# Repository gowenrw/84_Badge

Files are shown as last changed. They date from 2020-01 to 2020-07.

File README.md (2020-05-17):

# 84_Badge

This is where all the files for 84_Badge will be stored.  
This includes code and art and cad and fab files.  All the things.

View the web based Documentation here https://84badge.com

## File Structure

This is the file structure of this repository

* [/](/README.md) - YOU ARE HERE
* [/art/](./art/) - Artwork and other graphics created by this project
  * ./inspiration/ - Art and graphics pulled from other sources used as inspiration for this project
* [/code/](./code/) - All project related Code / Firmware
  * ./dev/ - Code folder for initial development PCB(s)
  * ./prod/ - Code folder for the production PCB(s)
  * ./include/ - Common code includes (e.g. chipset drivers, etc.) used by the other code folders
* [/docs/](./docs/) - Documentation created by this project including web pages
* [/eda/](./eda/) - Electronic Design Automation files (i.e. KiCad)
  * ./dev/ - KiCad project folder for initial development PCB(s)
  * ./prod/ - KiCad project folder for the production PCB(s)
* [/reference_parts/](./reference_parts/) - Documentation pulled from other sources related to components
* [./README.md](/README.md) - This File
* [./LICENSE](/LICENSE) - Currently set to MIT

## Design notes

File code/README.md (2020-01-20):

# Code

This is where all the all project related Code / Firmware is located

## File Structure

This is the file structure of this repository

* [/](/README.md) - Home
* [/code/](/code/) - YOU ARE HERE
  * [/code/dev/](/code/dev/) - Code folder for initial development PCB(s)
  * [/code/prod/](/code/prod/) - Code folder for the production PCB(s)
  * [/code/include/](/code/include/) - Common code includes (e.g. chipset drivers, etc.) used by the other code folders

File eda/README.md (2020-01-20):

# Electronic Design Automation

This is where all the Electronic Design Automation files for the PCB(s) will be stored.
The EDA used is KiCad 5.x unless otherwise specified.

The KiCad projects have been configured to use local libraries for long term sustainability per the best practices listed [HERE](https://hackaday.com/2017/05/18/kicad-best-practises-library-management/) and elsewhere.

## File Structure

This is the file structure of this repository

* [/](/README.md) - Home
* [/eda](/eda/) - YOU ARE HERE
  * [/eda/dev/](/eda/dev/) - KiCad project folder for initial development PCB(s)
    * ./3d_models/ - This directory contains footprint 3d model files
    * ./gerber/ - This directory contains gerber formatted files for manufacturing
    * ./lib_fp/ - This directory contains footprint module directories
    * ./lib_sh/ - This directory contains schematic library files
    * ./snapshots/ - This directory contains prints of schematic / cad files and images of preview / final product
  * [/eda/prod/](/eda/prod/) - KiCad project folder for the production PCB(s)
    * ./3d_models/ - This directory contains footprint 3d model files
    * ./gerber/ - This directory contains gerber formatted files for manufacturing
    * ./lib_fp/ - This directory contains footprint module directories
    * ./lib_sh/ - This directory contains schematic library files
    * ./snapshots/ - This directory contains prints of schematic / cad files and images of preview / final product

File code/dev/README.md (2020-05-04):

# Code / Dev

Code folder for initial development PCB(s)

Currently contains example code for the 84 Badge development PCB

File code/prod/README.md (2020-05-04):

# Code / Prod

Code folder for the production PCB(s)

Currently contains the following code:
* Example code for the 84 badge PCB
* Production code for the 84 badge PCB

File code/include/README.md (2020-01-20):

# Code Includes

Common code includes (e.g. chipset drivers, etc.) used by the other code folders

This folder currently contains the CH55x micro controller include files taken from the [Blinkinlabs Repository](https://github.com/Blinkinlabs/ch554_sdcc)

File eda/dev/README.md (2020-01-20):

# Electronic Design Automation / Development PCB(s)

KiCad project folder for initial development PCB(s)

## File Structure

This is the file structure of this repository

* [/](/README.md) - Home
* [/eda](/eda/) - Electronic Design Automation files (i.e. KiCad)
  * [/eda/dev/](/eda/dev/) - YOU ARE HERE
    * ./<filename>.pro - project file. Holds parameters that apply to the entire project (e.g. schematic, PCB layout, etc.).
    * ./<filename>.sch - schematic file.
    * ./<filename>.kicad_pcb - the PCB New layout file.
    * ./<filename>.net - netlist in "Pcbnew" format
    * ./<filename>.bak - backup of schematic file.
    * ./<filename>.kicad_pcb-bak - backup of the new PCB layout file.
    * ./<filename>-cache.lib - a local cache copy of all the symbols used in the schematic
    * ./fp-lib-table - Footprint library list
    * ./sym-lib-table - Schematic library list
    * [./3d_models/](/eda/dev/3d_models/) - This directory contains footprint 3d model files
    * [./gerber/](/eda/dev/gerber/) - This directory contains gerber formatted files for manufacturing
    * [./lib_fp/](/eda/dev/lib_fp/) - This directory contains footprint module directories
    * [./lib_sh/](/eda/dev/lib_sh/) - This directory contains schematic library files
    * [./snapshots/](/eda/dev/snapshots/) - This directory contains prints of schematic / cad files and images of preview / final product

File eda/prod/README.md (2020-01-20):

# Electronic Design Automation / Production PCB(s)

KiCad project folder for the production PCB(s).

## File Structure

This is the file structure of this repository

* [/](/README.md) - Home
* [/eda](/eda/) - Electronic Design Automation files (i.e. KiCad)
  * [/eda/prod/](/eda/prod/) - YOU ARE HERE
    * ./<filename>.pro - project file. Holds parameters that apply to the entire project (e.g. schematic, PCB layout, etc.).
    * ./<filename>.sch - schematic file.
    * ./<filename>.kicad_pcb - the PCB New layout file.
    * ./<filename>.net - netlist in "Pcbnew" format
    * ./<filename>.bak - backup of schematic file.
    * ./<filename>.kicad_pcb-bak - backup of the new PCB layout file.
    * ./<filename>-cache.lib - a local cache copy of all the symbols used in the schematic
    * ./fp-lib-table - Footprint library list
    * ./sym-lib-table - Schematic library list
    * [./3d_models/](/eda/prod/3d_models/) - This directory contains footprint 3d model files
    * [./gerber/](/eda/prod/gerber/) - This directory contains gerber formatted files for manufacturing
    * [./lib_fp/](/eda/prod/lib_fp/) - This directory contains footprint module directories
    * [./lib_sh/](/eda/prod/lib_sh/) - This directory contains schematic library files
    * [./snapshots/](/eda/prod/snapshots/) - This directory contains prints of schematic / cad files and images of preview / final product

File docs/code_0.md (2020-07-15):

---
title: Code
has_children: true
nav_order: 4
---

# The Code of the 84 Badge

On this page I will review the badge code for both the development board and the badge PCB.
Both boards have the same electronics and the code works on both.
But the dev board code was to simply test the electronics and had more simple code compared to the badge code.

The Micro Controller used is a CH552G.
The CH55x series of Micro Controllers are based off of an ARM 8051 chipset and can be programmed using [Kiel C51](http://www.keil.com/c51/) or [SDCC](http://sdcc.sourceforge.net/).
I use SDCC (Small Device C Compiler) and will get into more specifics about that on the next page.

## Development board code

For the development board I just needed a quick and dirty test of the electronics.  So I created a simple blink program that will blink the LEDs by color group.

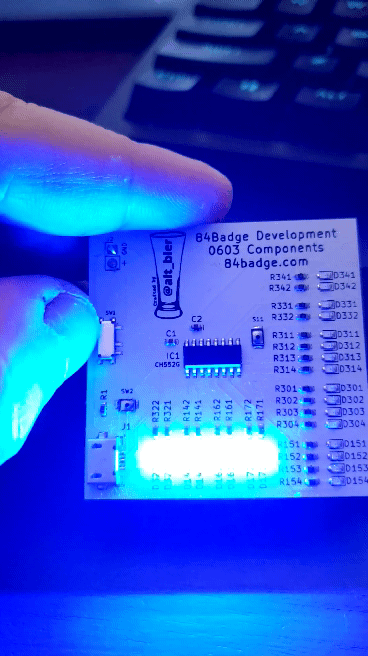
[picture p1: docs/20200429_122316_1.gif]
Dev_Board


The way the pins are laid out on the CH552G chip are by major pin and sub-pin (e.g. 1.1, 1.2, 3.1, 3.2, etc.).  

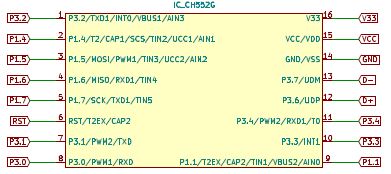
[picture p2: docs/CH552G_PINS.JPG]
CH552G_Pins


So the first things that I have to do is include the Micro Controller header file ch554.h and define the pins followed by setting the SBIT for those pins.  
Note: SBITs refer to the bits that have SFRs (special function registers) on the Micro Controller.

```c
#include <ch554.h>
.
.
#define LEDY30_PIN 0
#define LEDR31_PIN 1
#define LEDB32_PIN 2
#define LEDR33_PIN 3
#define LEDR34_PIN 4
.
.
// P1 = 0x90 P3 = 0xB0
SBIT(LEDY30, 0xB0, LEDY30_PIN);
SBIT(LEDR31, 0xB0, LEDR31_PIN);
SBIT(LEDB32, 0xB0, LEDB32_PIN);
SBIT(LEDR33, 0xB0, LEDR33_PIN);
SBIT(LEDR34, 0xB0, LEDR34_PIN);
.
.
```

With the preliminary setup done I can set up the main function and set those pins up as GPIO (general purpose input and output) pins by calling defined SFR references from the Micro Controller header file ch554.h

```c
void main() {
  .
  .
  // Configure pin 3.0 as GPIO output
  P3_MOD_OC = P3_MOD_OC & ~(1<<LEDY30_PIN);
  P3_DIR_PU = P3_DIR_PU |	(1<<LEDY30_PIN);
  // Configure pin 3.1 as GPIO output
  P3_MOD_OC = P3_MOD_OC & ~(1<<LEDR31_PIN);
  P3_DIR_PU = P3_DIR_PU |	(1<<LEDR31_PIN);
  // Configure pin 3.2 as GPIO output
  P3_MOD_OC = P3_MOD_OC & ~(1<<LEDB32_PIN);
  P3_DIR_PU = P3_DIR_PU |	(1<<LEDB32_PIN);
  // Configure pin 3.3 as GPIO output
  P3_MOD_OC = P3_MOD_OC & ~(1<<LEDR33_PIN);
  P3_DIR_PU = P3_DIR_PU |	(1<<LEDR33_PIN);
  // Configure pin 3.4 as GPIO output
  P3_MOD_OC = P3_MOD_OC & ~(1<<LEDR34_PIN);
  P3_DIR_PU = P3_DIR_PU |	(1<<LEDR34_PIN);
  .
  .
```

Here is an excerpt from ch554.h that defines those SFR references.

```c
SFR(P3_MOD_OC,	0x96);	// port 3 output mode: 0=push-pull, 1=open-drain
SFR(P3_DIR_PU,	0x97);	// port 3 direction for push-pull or pullup enable for open-drain
```

All that is left is to create a loop to turn the LEDs on and off with a delay.

```c
while (1) {
  // Setting the LEDs to on or off
  LEDY30 = 1;
  LEDY15 = 1;
  LEDR31 = 0;
  LEDR33 = 0;
  LEDR34 = 0;
  LEDB32 = 0;
  LEDB14 = 0;
  LEDB16 = 0;
  LEDB17 = 0;
  // Delay controls blink speed
  mDelaymS(300);
  .
  .
```

This is a simple but effective way for me to test out all the electronics on the board.

## 84 Badge code

For the badge code I needed to do a bit more work to get the groups of LEDs to light in the order I wanted them to fire for the effect I was going for.
In addition I needed to program the button to change LED modes and come up with a few different LED patterns to switch between.

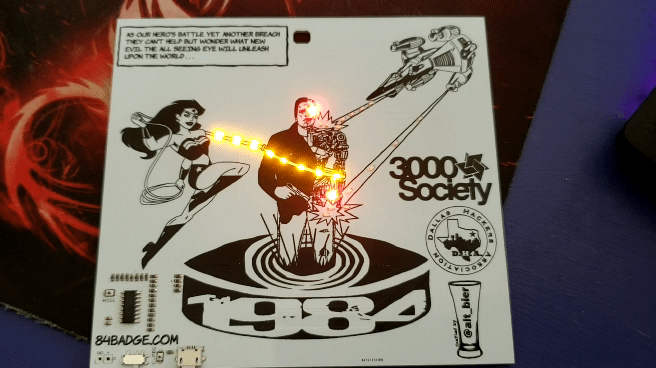
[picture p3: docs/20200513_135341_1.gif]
84_Badge_Board


I start this code the same way I did for the development board.
I include the Micro Controller header file ch554.h and define the pins followed by setting the SBIT for those pins.
For this board I must also define a couple of variables for the button operations.

```c
#include <ch554.h>
.
.
// define the sub-pins for pin 3
#define LEDY30_PIN 0
#define LEDR31_PIN 1
#define LEDB32_PIN 2
#define LEDR33_PIN 3
#define LEDR34_PIN 4
// define the sub-pins for pin 1
#define BUTTON11_PIN 1
.
.
// assign sub-pins to pins
// P1 = 0x90 P3 = 0xB0
SBIT(LEDY30, 0xB0, LEDY30_PIN);
SBIT(LEDR31, 0xB0, LEDR31_PIN);
SBIT(LEDB32, 0xB0, LEDB32_PIN);
SBIT(LEDR33, 0xB0, LEDR33_PIN);
SBIT(LEDR34, 0xB0, LEDR34_PIN);
SBIT(BUTTON11, 0x90, BUTTON11_PIN);
.
.
// 1 byte integer for putton push flag - no bool type available
uint8_t button11push=0;

// 1 byte integer for LED Mode (controlled by button)
// Modes 1 is the default start mode
uint8_t ledmode=1;
.
.
```

With the preliminary setup done I can set up the main function and set the LED pins up as GPIO (general purpose input and output) pins by calling defined SFR references from the Micro Controller header file ch554.h

```c
void main() {
  .
  .
    // setup pin 3
    // Configure pin 3.0 as GPIO output
    P3_MOD_OC = P3_MOD_OC & ~(1<<LEDY30_PIN);
    P3_DIR_PU = P3_DIR_PU |	(1<<LEDY30_PIN);
    // Configure pin 3.1 as GPIO output
    P3_MOD_OC = P3_MOD_OC & ~(1<<LEDR31_PIN);
    P3_DIR_PU = P3_DIR_PU |	(1<<LEDR31_PIN);
    // Configure pin 3.2 as GPIO output
    P3_MOD_OC = P3_MOD_OC & ~(1<<LEDB32_PIN);
    P3_DIR_PU = P3_DIR_PU |	(1<<LEDB32_PIN);
    // Configure pin 3.3 as GPIO output
    P3_MOD_OC = P3_MOD_OC & ~(1<<LEDR33_PIN);
    P3_DIR_PU = P3_DIR_PU |	(1<<LEDR33_PIN);
    // Configure pin 3.4 as GPIO output
    P3_MOD_OC = P3_MOD_OC & ~(1<<LEDR34_PIN);
    P3_DIR_PU = P3_DIR_PU |	(1<<LEDR34_PIN);
  .
  .
```

The last section of code took the most time as I had to create my loop and have it check for an LED mode and a button push which would change that LED mode.

```c
// ********************************
// ********* Primary Loop *********
// ********************************
while (1) {
    // ********************************
    // ********** LED MODE 3 **********
    // ********************************
    if (ledmode == 3) {
      // *****
      // ***** This mode keeps all LEDs ON
      // *****
      // Delay to display previous LED state
      mDelaymS(300);
      // If we see button push set button push flag
      if (BUTTON11 == 0) { button11push = 1; }
      // ***** Set LED states to on or off
      LEDY30 = 1, LEDY15 = 1, LEDR31 = 1, LEDR33 = 1, LEDR34 = 1, LEDB32 = 1, LEDB14 = 1, LEDB16 = 1, LEDB17 = 1;
      // ***** End of this LED mode
    }
    // ********************************
    // ********** LED MODE 2 **********
    // ********************************
    if (ledmode == 2) {
      .
      .
      // ***** End of this LED mode
      // *****
    }
    // ********************************
    // ***** LED MODE ADJUSTMENTS *****
    // ********************************
    // If button was pushed during the cycle above then flag should be set
    if (button11push == 1) {
      // Increase LED Mode value
      ledmode = ledmode + 1;
      // Check if LED Mode value is beyond max value and if so set to min value
      if (ledmode > 3) { ledmode = 1; }
      // Reset button push flag
      button11push = 0;
    }
    // ********************************
    // ****** END OF MODE LOOPS *******
    // ********************************
}
// ********************************
// ***** END OF PRIMARY LOOP ******
// ********************************
```

On each delay I would look for the button being pushed and if it was then I would set the variable button11push to 1 which would trigger the incrementing of the ledmode variable and the reset of the button11push variable at the end of the current LED mode loop iteration.

Most of the code is in the LED mode 1 which is the default LED mode and the one with the most complex pattern for the artwork effect.

In order to plan out how I wanted the LEDs to turn on or off for this LED mode I used google sheets.
I laid out the LEDs with conditional formatting and some scripting that would spit out the bit of code needed for each LED transition.

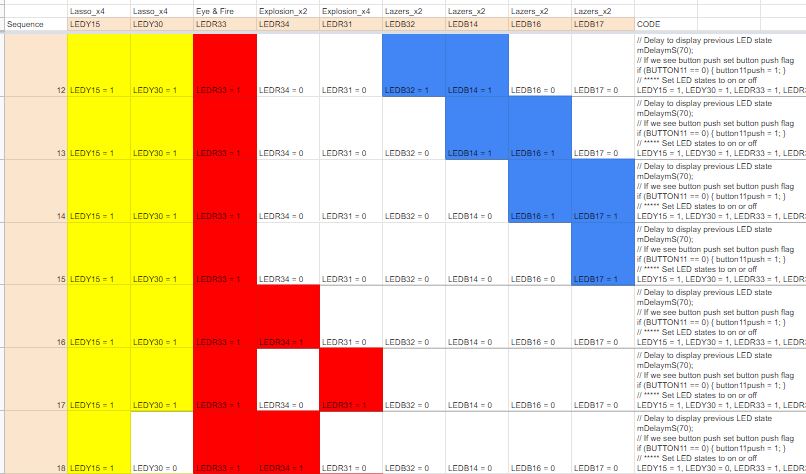
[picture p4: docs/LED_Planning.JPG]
LED_Planning


I think it turned out fairly well.
But I am looking at changing the yellow LEDs to use a PWM setting instead of simple on/off to provide more of a glowing effect.

This is the end of the code review.

Thanks for reading it.

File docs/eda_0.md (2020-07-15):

---
title: EDA
has_children: true
nav_order: 5
---

# The EDA work on the 84 Badge

This section is where I will review the Electronic Design Automation work done to produce the PCB(s) for the badge and its development board.

On this page I'll review the EDA software I used, the process I follow, and the file layout I used, and the reason I decided on a development board for the project.
On the following pages I will detail the schematic and PCB layouts of the 84 Badge and its development board.

## KiCad

I used [KiCad 5.1](https://kicad-pcb.org/) as my EDA program for this badge.

I configure my KiCad projects to use local libraries for long term sustainability per the best practices listed [HERE](https://hackaday.com/2017/05/18/kicad-best-practises-library-management/) and elsewhere.

Beyond the fact that I use some components that are not in the default KiCad libraries, copying the default components I use into my local project libraries ensures that if KiCad makes changes in the future, my projects will retain the original versions of these components keeping them compatible.

What this means for you is that when you download my project and open it up in KiCad you will have all the same exact component symbol and footprint and 3D model files available to you that I did when I created the project.

## My Process

The process I use when building a PCB in an KiCad is as follows:
* Create the file structure for the project
  * Note: I use a project template github repo to simplify this process as it has all the directories primed with README files.
* Build out the local libraries with any components I know I plan to use. (Others will be added to these libraries as identified)
  * Note: I use a project template github repo to simplify this process that contains most of the generic components I would use built into generic blank KiCad project files.
* Create the electrical schematic and output a netlist
* Create the PCB layout file starting with that netlist
  * This populates the PCB file with all the components from the schematic along with thier associated connection points that will need traces.
* Import the artwork into the silkscreen layers of the PCB
* Arrange the componets on the PCB and lay down the traces and vias
* Generate gerber output files of the PCB
* Send gerber files for manufacturing

## File Layout

This is the file layout I use for any PCB EDA project using KiCad.
Note that I break out development and production boards in thier own directory spaces.
* /eda/ - Electronic Design Automation files (i.e. KiCad)
  * /eda/dev/ - Development PCB
  * or
  * /eda/prod/ - Production PCB
    * ./<filename>.pro - project file. Holds parameters that apply to the entire project (e.g. schematic, PCB layout, etc.).
    * ./<filename>.sch - schematic file.
    * ./<filename>.kicad_pcb - the PCB New layout file.
    * ./<filename>.net - netlist in "Pcbnew" format
    * ./<filename>.bak - backup of schematic file.
    * ./<filename>.kicad_pcb-bak - backup of the new PCB layout file.
    * ./<filename>-cache.lib - a local cache copy of all the symbols used in the schematic
    * ./fp-lib-table - Footprint library list
    * ./sym-lib-table - Schematic library list
    * ./3d_models/ - This directory contains footprint 3d model files
    * ./gerber/ - This directory contains gerber formatted files for manufacturing
    * ./lib_fp/ - This directory contains footprint module directories
    * ./lib_sh/ - This directory contains schematic symbol library files
    * ./snapshots/ - This directory contains prints of schematic / cad files and images of preview / final product

## Development Board

I had an idea of how I wanted the electronics of the badge to be designed, but I needed to test it for several reasons.

This would be only my second time designing a board with the CH552G chip and this would triple the number of LEDs I had previously used.

In addition, I've never used components as small as the SMD 0603 before and had doubt's that I could place the parts by hand (Oh how I wish I could afford a pick and place machine).

The problem was that I was weeks away from having the artwork ready and needed to test my ideas sooner in case it didn't work and needed to be redesigned which might impact the artwork.

So rather than waiting for all the artwork to be done to do a prototype of the full badge I decided to make a development board that would have the same electronics but on a smaller scale without artwork.

It turns out that my electronics design was solid and I was able to place those tiny parts without too much trouble.
So, I just carried this forward to the badge design without change.

This means both the development board and the badge share the same electronics schematic and can use the same code.

This turned out to be an advantage as while I was waiting on the badge prototypes to arrive I was writing code and testing it using the development board.

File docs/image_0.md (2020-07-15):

---
title: Images
nav_order: 2
---

# Images of the badge

84 Badge Front

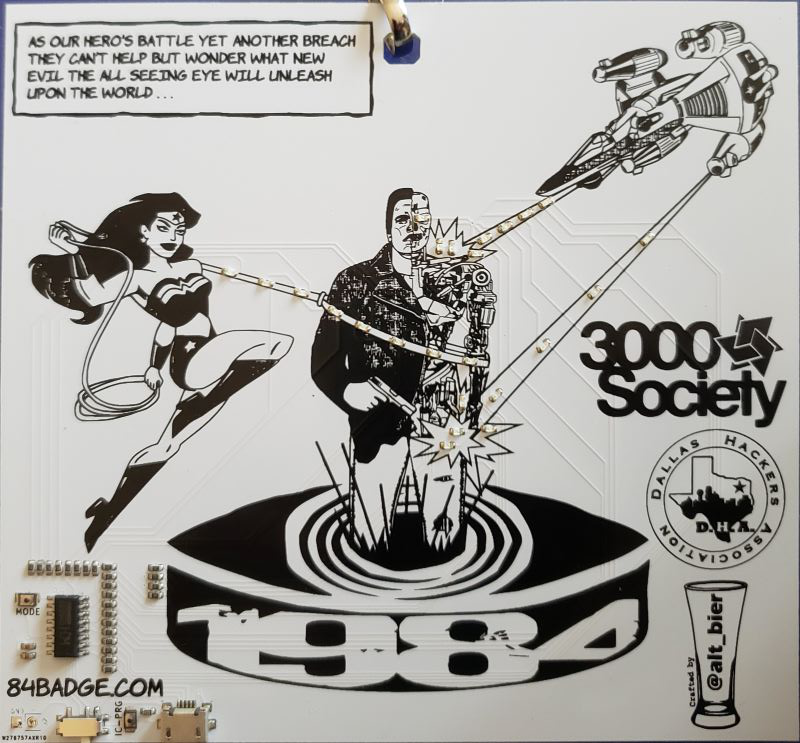
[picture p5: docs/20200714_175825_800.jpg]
Badge_front


84 Badge Back

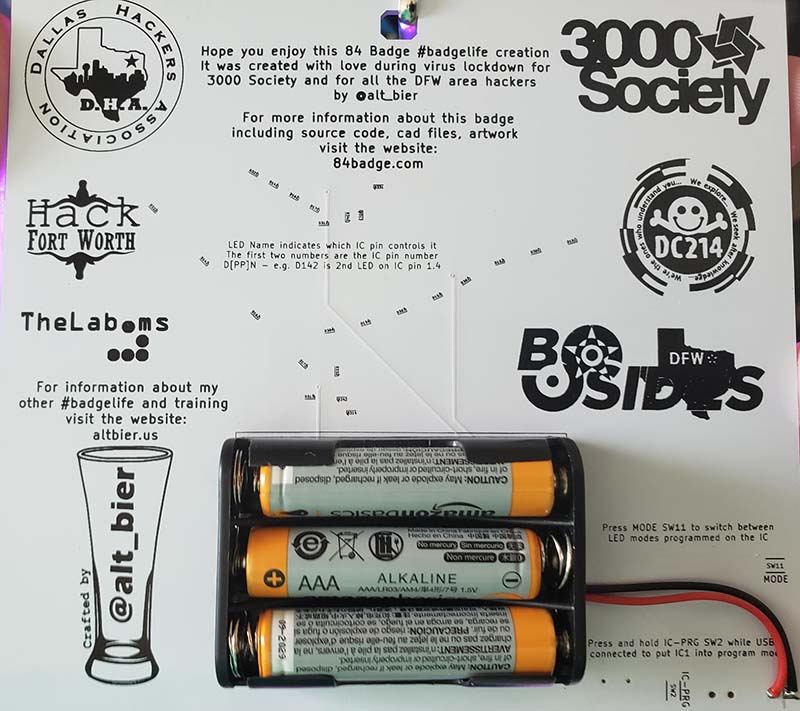
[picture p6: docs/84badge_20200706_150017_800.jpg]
Badge_back


84 Badge Front with all LEDs lit

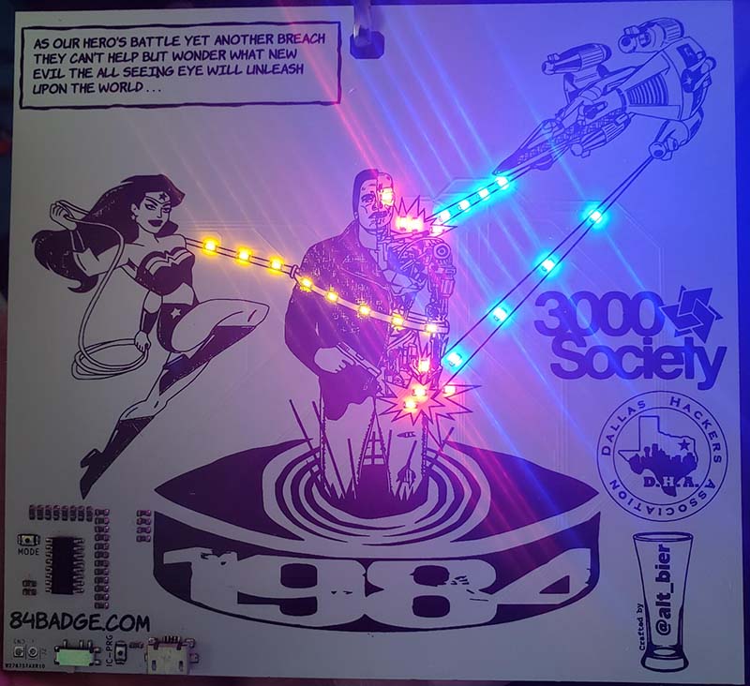
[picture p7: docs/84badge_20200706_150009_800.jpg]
Badge_front_lit


84 Badge Front with LEDs lit Animated

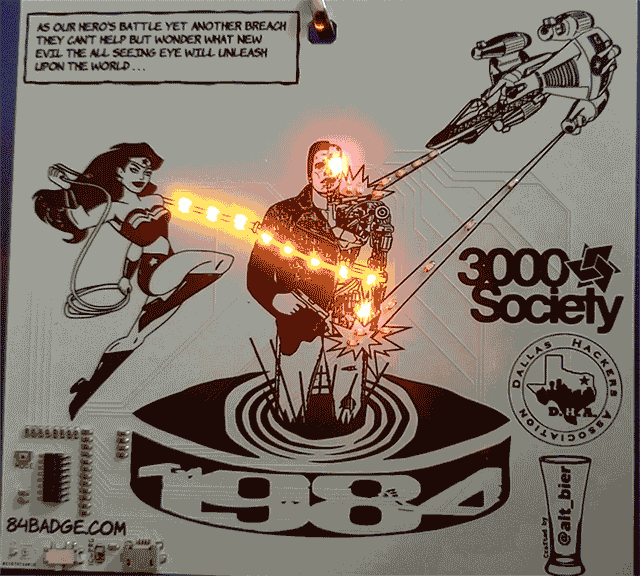
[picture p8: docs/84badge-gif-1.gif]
Badge_front_lit_gif


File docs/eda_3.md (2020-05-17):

---
title: Prod PCB
parent: EDA
nav_order: 3
---

# The EDA work on the 84 Badge - Prod PCB

The production board was a much more difficult proposition than the development board even with tested electronics.

I had to size it to present the artwork properly and fit all the components onto the PCB in such a way as to not detract from that artwork.

## PCB Layout

I decided to put most of the components in a corner where they would be out of the way of the artwork.

This had the added effect of becoming part of the artwork as the resistors appear to make a sort of box that Wonder Woman is launching herself from.

It also helped in my assembly since having most of the components in a small area of the PCB allowed my manual pick and place machine (my hands holding tweezers) to get the parts on the board faster.

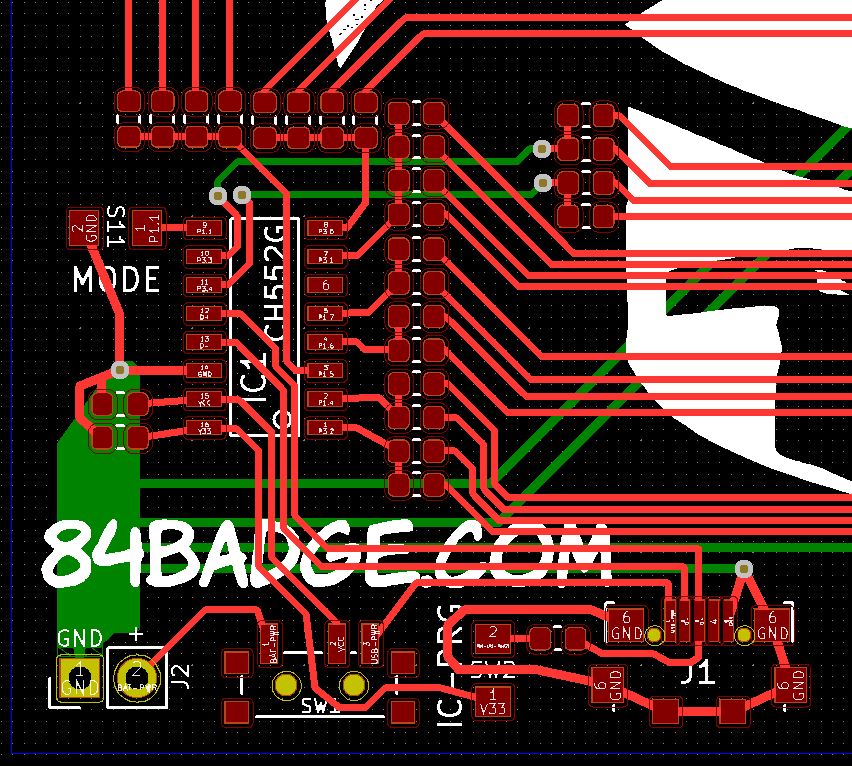
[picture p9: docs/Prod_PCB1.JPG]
Prod_PCB1


With most of the components in the corner done I focused on placing the LEDs next.

I had three different colors of LEDs grouped in different quantities to serve different purposes.  
So, I had to match up the exact LED I wanted in each place within the artwork of the board.

In some cases this was easy to do.

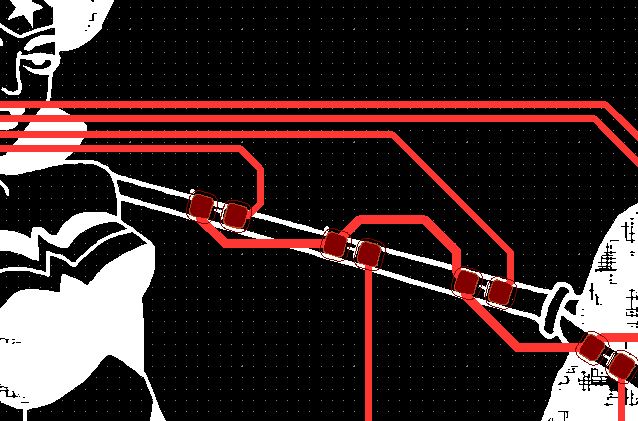
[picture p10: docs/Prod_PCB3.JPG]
Prod_PCB3


In some cases this was more difficult.

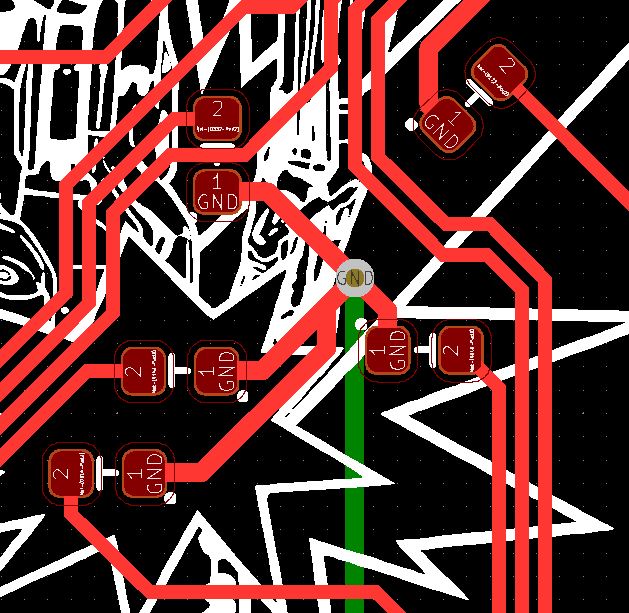
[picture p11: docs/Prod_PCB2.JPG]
Prod_PCB2


Once the LEDs were placed I had to run all the traces to them.

This was challenging because unlike on my development board I wasn't lining these up in neat lines but rather all over the board.

The help with this and avoid complicated routing I put the ground traces on the back of the board and used vias to connect them to the front.

To minimize the number of vias needed I chained several LED grounds together to be routed to a ground via.

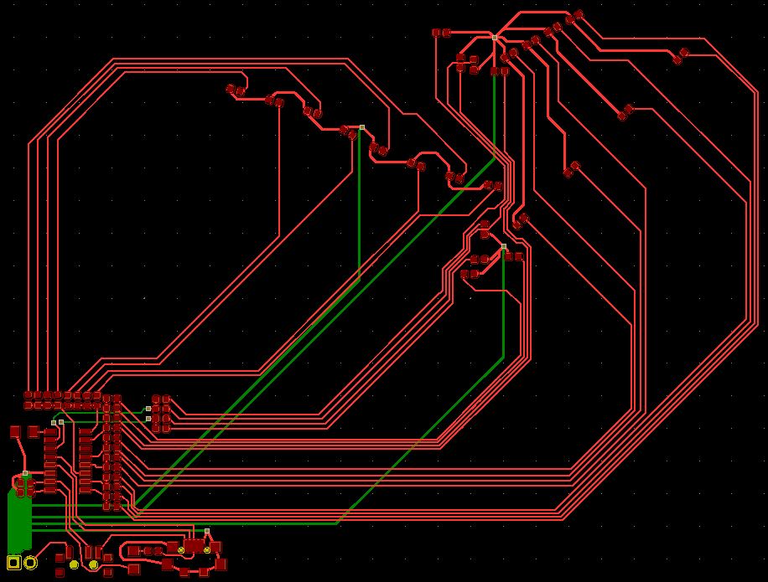
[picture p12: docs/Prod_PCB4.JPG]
Prod_PCB4


Once all the placement and trace routing was complete I added some logo's and some text to the back of the board and it was finished.

This completes the Prod PCB review.

[You can download a PDF of the Prod PCB file here.](https://github.com/gowenrw/84_Badge/raw/master/eda/prod/snapshots/84badge_prod_pcb.pdf)

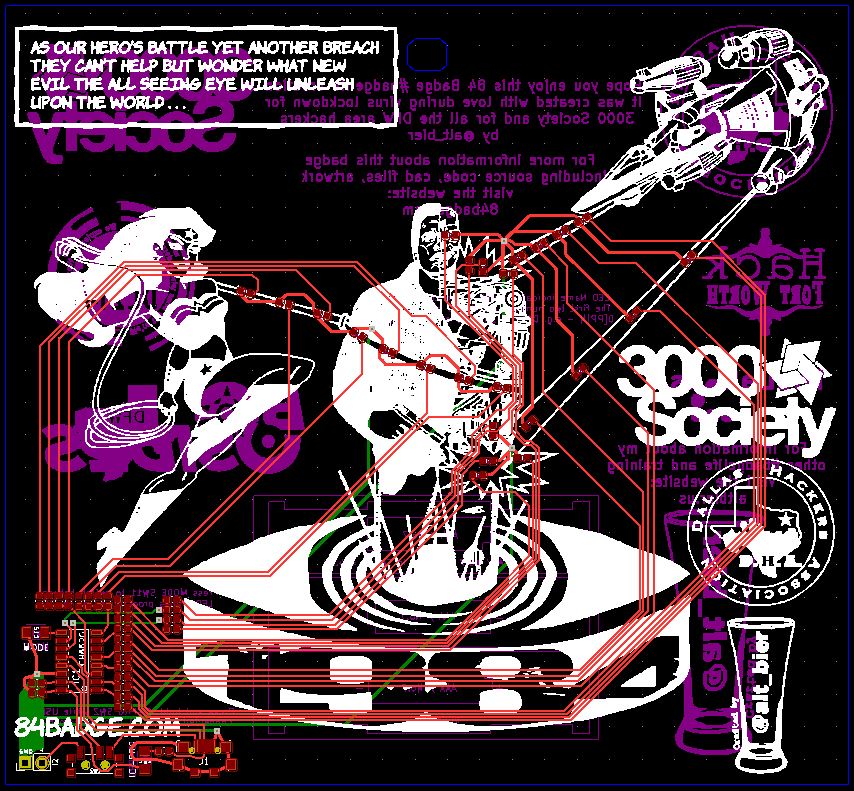
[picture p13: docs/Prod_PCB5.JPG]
Prod_PCB5


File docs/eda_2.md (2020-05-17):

---
title: Dev PCB
parent: EDA
nav_order: 2
---

# The EDA work on the 84 Badge - Dev PCB

The development board was just a quick way to test out the electronics.
So, I wanted to keep it a small and simple as possible to keep manufacturing costs to a minimum.

## PCB Layout

As it turns out I was able to get all the components to fit into a 48mm (1.9in) square.

I was also able to get all the traces onto one layer so that no vias were required.

It was a tight fit but everything worked perfectly enough that I was able to move the electrical design to the prod project with no modifications.

This completes the Dev PCB review (it was simple so there was not much to review).

[You can download a PDF of the Dev PCB file here.](https://github.com/gowenrw/84_Badge/raw/master/eda/dev/snapshots/84badge_dev_pcb.pdf)

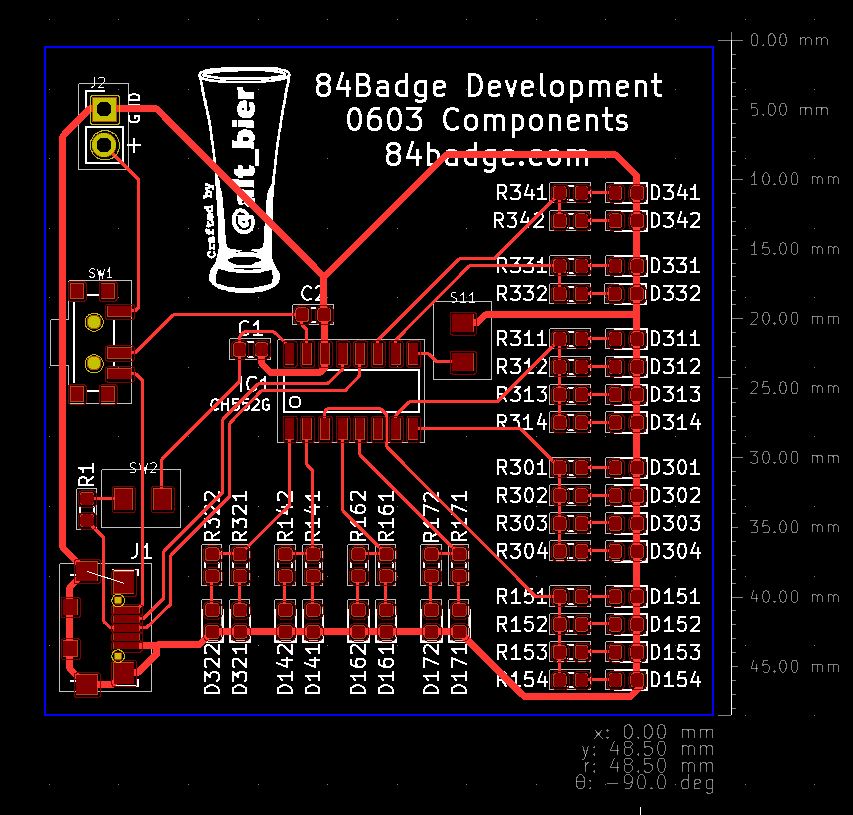
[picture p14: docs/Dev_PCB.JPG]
Dev_PCB


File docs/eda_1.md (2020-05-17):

---
title: Schematic
parent: EDA
nav_order: 1
---

# The EDA work on the 84 Badge - Schematic

The schematic work usually takes me just as long as the PCB work since it is during the schematic design process that I identify new components I will be using.

I believe that the electrical schematic design is the most important part of the process since no amount of work in the PCB design can fix a flawed electrical design.

## Component Design Files

When I identify a new component I'll be using, even one as simple as a resistor, I take the time during schematic design to copy the component schematic symbol and footprint and 3d model files to the local project library, or create them from scratch if they don't exist in the KiCad library.

It is important to note that the three component design file types can be interconnected for convinience.
A schematic symbol file can reference a footprint file which can reference a 3d model file.
I take the time now to incorporate these references as it saves time later.

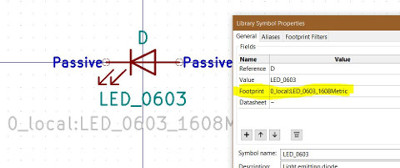
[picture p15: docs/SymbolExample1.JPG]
Symbol

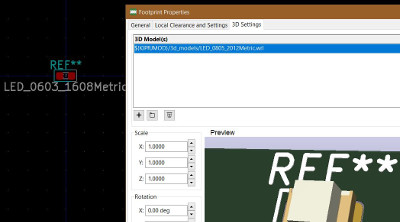
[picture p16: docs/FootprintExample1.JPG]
Footprint


Having previously worked with the CH552G Micro Controller I was aware of all the basics to design with it.

On my previous design for the BSidesDFW conference badge I built from scratch the schematic symbol and footprint and 3D model for this chip and other components it required (USB connector, power switch, etc.).

This left just the new 0603 components I needed to add to the local project library.
These were all readily available in the KiCad library and was just a matter of copying over.

## Schematic Design

The first thing that I put into the schematic design was the CH552G IC and its basic required components since I knew this part of the design from my previous badge creation.

This IC requires a USB connector, two capacitors for regulating the 3.3V and 5V signals, a 10K pull up resistor tied to a tactile switch which will put the IC into programming mode, and finally a toggle switch to control Battery vs. USB power source.

I placed the IC and its basic required components together into a CH552G boilerplate section that I will be able to reuse in future projects.

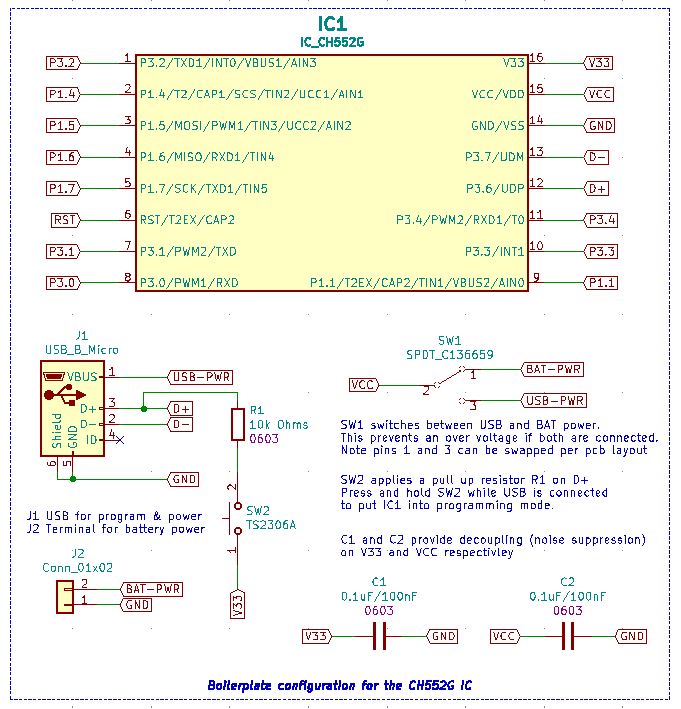
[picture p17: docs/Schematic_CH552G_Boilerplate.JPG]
CH552G_Boilerplate


With this done I focused on the remaining tactile switch and the 24 LEDs with thier supporting resistors.

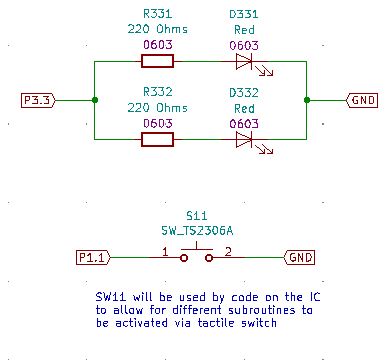
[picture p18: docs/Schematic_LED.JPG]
LEDs


Given that I was going to require more LEDs than the number of IC pins I had to control them I grouped the LEDs in parallel on each IC pin.
This grouping has all 24 LEDs controlled by 9 pins on the IC.
These groupings were not all equal as I grouped them based on thier functionality in the badge design.

This completes the schematic review.

[You can download a PDF of the schematic file here.](https://github.com/gowenrw/84_Badge/raw/master/eda/prod/snapshots/84badge_prod_schematic.pdf)

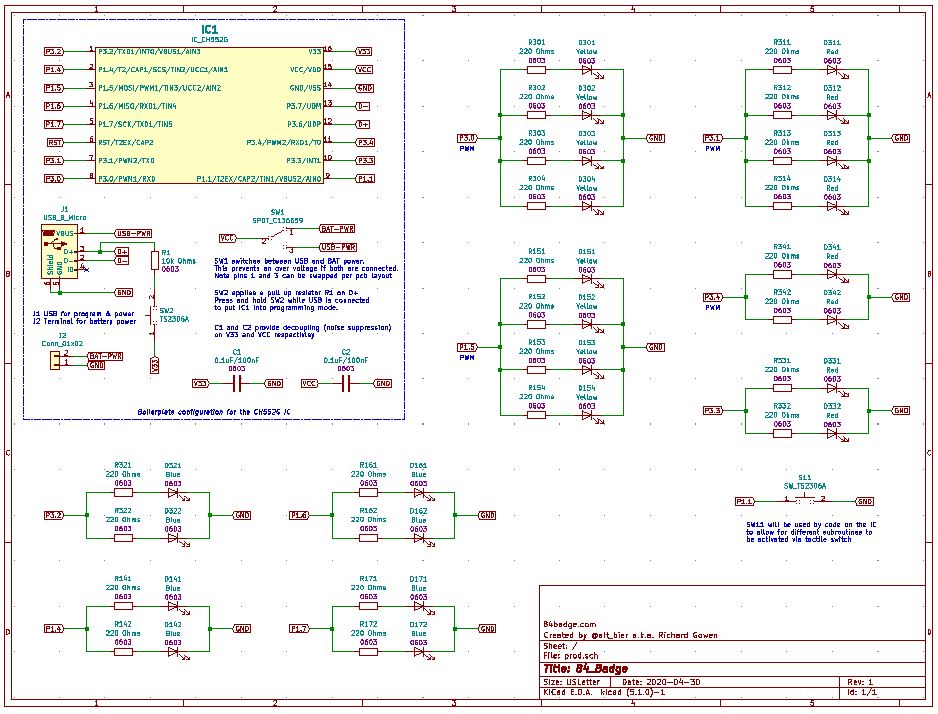
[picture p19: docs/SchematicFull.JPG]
SchematicFull


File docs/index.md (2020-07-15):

---
title: Home
nav_order: 1
---

# 84 Badge

Welcome to the 84 badge resource page.

This is where you will find all the details about this badge.

This includes concept and art and code and cad.

All the things.

I hope you enjoy this badge as much as I enjoyed making it.

-- [@alt_bier](https://twitter.com/alt_bier)  - [My Contact Info](https://gowen.net/about)

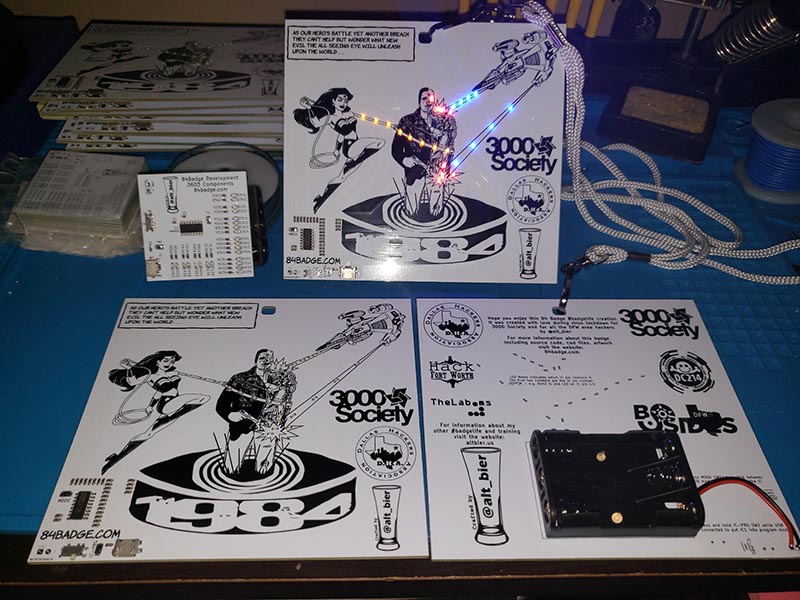
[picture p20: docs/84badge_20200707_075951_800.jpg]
Badge


I did a limited run of these badges (100) and will be selling them on eBay (link coming soon).
I will also be giving away a few.  So watch my twitter feed for giveaway details if you are interested.

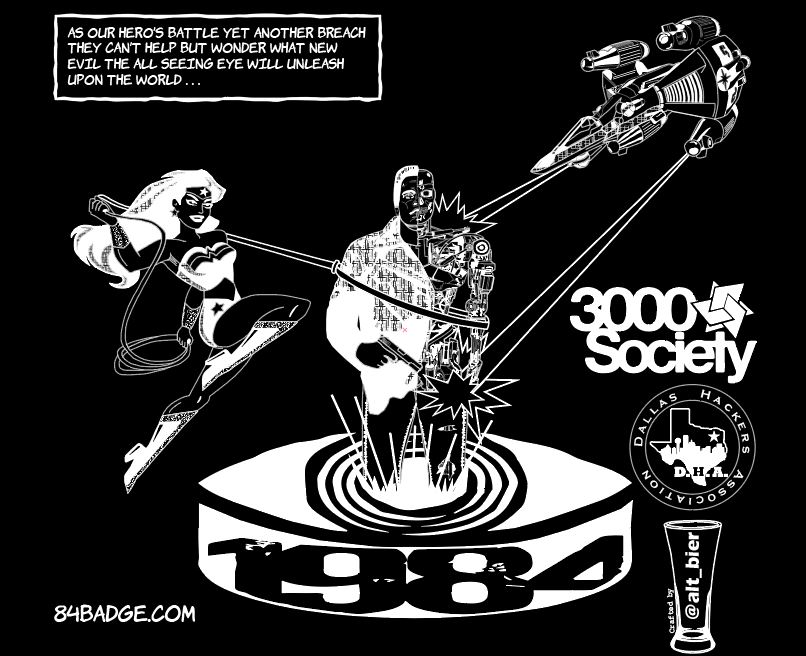
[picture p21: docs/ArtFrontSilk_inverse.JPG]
FrontSilk


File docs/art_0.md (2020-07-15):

---
title: Art
has_children: true
nav_order: 3
---

# The Art and Concept of the 84 Badge

## Concept

The concept for this badge was tied to the 3000 Society Game Con which was themed 1984 as it was scheduled to happen on the weekend of the new Wonder Woman 1984 movie release.

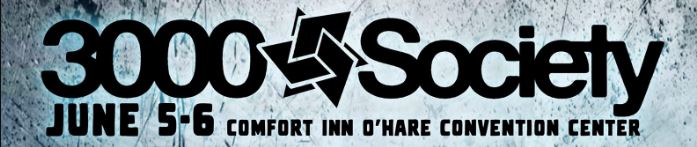
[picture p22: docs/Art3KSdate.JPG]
3000_Society

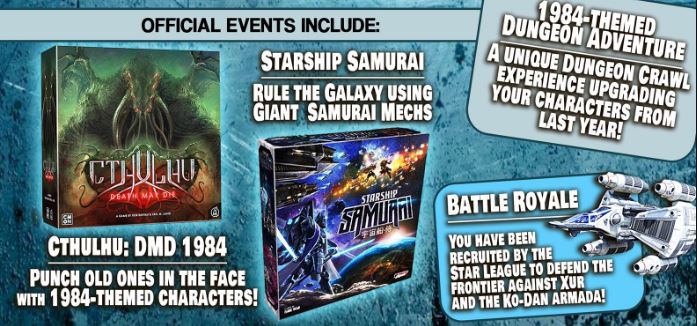
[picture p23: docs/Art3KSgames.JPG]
3000_Society_games


So I chose a 1984 theme for the badge which would include Wonder Woman.

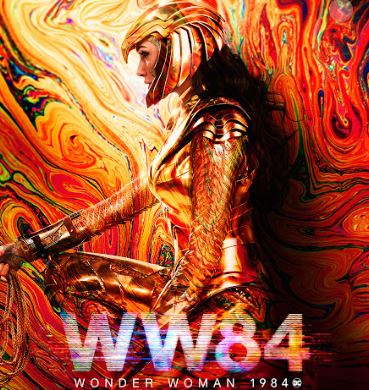
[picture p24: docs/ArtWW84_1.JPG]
WW84


I knew early on that I wanted to design the badge to look like a classic comic book cell: square, black on white, and a narrator's block or speech bubbles.
I wanted this badge to tell a story and like any good story it needed heroes and villains.

ComicCell

There were so many characters and things that were related to 1984 it took me a while to figure out what to include and how to make them work together with Wonder Woman.

I started by looking for villains and the two the jumped out at me were The Terminator (movie release and timeframe both 1984) and the evil state from George Orwell's 1984 (book timeframe is 1984).
I wanted to use both of them somehow.
The Terminator would be easy to incorporate, but how to represent an evil state and it's oppression of the people via surveillance?
Looking through some inspirational images searches I stumbled upon one of the many book covers for Orwell's 1984 which was just a huge eye.
Then it hit me that this was an 'All Seeing Eye' that could spew destruction.
I played around with having it shoot beams or something, but that didn't tie the villains together the way I wanted.
As I was struggling with this I read a tweet from someone in infosec I follow that mentioned a breach, and it hit me that the All Seeing Eye should be a breach in spacetime that is depositing the Terminator into 1984 for Wonder Woman to battle.

Next I focused on my heroes.
I didn't want Wonder Woman fighting alone, but at the same time I didn't want her partner to steal the show.
So, I needed a lesser hero or something abstract like the All Seeing Eye was for the villains and they/it needed to exist in 1984 or have some plausible reason for being there.
Being one of my favorite movies from that year, The Last Starfighter (movie release and timeframe both 1984) immediately came to mind.
The question became how to incorporate the two heroes.
I figured The Last Starfighter would have to be in his Gunstar in order to help at all against a Terminator.
So the Gunstar would be firing lasers, but what would Wonder Woman be bringing to the battle?
I figured that firing from atmosphere at a small fast target like a Terminator would make him next to impossible to hit.
So, Wonder Woman would have to get up close and personal with the Terminator to hold him in place with her magic lasso in order for The Last Starfigher to be able to hit the target.

My story was complete and the narrator's text basically wrote itself including the ironic way it could just as easily been referencing Information Security heroes fighting a data breach based on modern surveillance.

Narrator_Text

One note on that text: I know that "Heroes" is the correct spelling.  But, it looked odd when I had it typed out and I thought that "Hero's" looked better.  Call it artistic license.

## Art

For the artwork I started by looking for inspiration via google image searches.  As you can imagine there were many images related to Wonder Woman, The Terminator, The Last Starfighter, and George Orwell's 1984.

Inspiration

I struggled with the font for the narrator text.  I finally found one I liked that is called Komika.  It looked to be the closest I could get to the text used in old school comics.

Komika

Once I had an idea of how I wanted to represent each of my characters and the font I would use, I started the work of drawing the art using Adobe Illustrator.  
Using a combination of free hand and trace work and several different shading techniques (necessary to keep it truly black on white without shades of grey) I was able to bring it all together.
Once I finished adding a few logo's it was complete.

FrontSilk

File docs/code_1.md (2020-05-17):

---
title: Working with the code
parent: Code
nav_order: 1
---

# Working with the code of the 84 Badge

On this page I will provide details on how to work with the code, get it compiled, and finally how to download that code to the Micro Controller.

## How to program the CH55x Micro Controller

The CH55x series of Micro Controllers are based off of an ARM 8051 chipset and can be programmed using [Kiel C51](http://www.keil.com/c51/) or [SDCC](http://sdcc.sourceforge.net/).

I will document here how I was able to set up both a Windows and a Linux box to program this chip using SDCC (Small Device C Compiler).

Here is a link to some good documentation on OpenSource SDCC and the CH55x SDK https://github.com/Blinkinlabs/ch554_sdcc

### Windows Setup

Here are the steps I followed to get the toolchain fully set up to compile and push code to the CH55x chips on my Windows box.

* Download and Install [Git for Windows](https://gitforwindows.org/) which provides a git-bash CLI that will be used to download and compile the code.
* Download and Install [SDCC](http://sdcc.sourceforge.net/) using the [latest version here](https://sourceforge.net/projects/sdcc/files/latest/download?source=files)
* Download and Install [MinGW - Minimalist GNU compiler for Windows](https://sourceforge.net/projects/mingw/) using the [latest version here](https://downloads.sourceforge.net/project/mingw/Installer/mingw-get-setup.exe)
* Download and Install the [WCHISPTOOL from the chip manufacturer wch.cn](http://wch.cn/download/WCHISPTool_Setup_exe.html) which will be used to push compiled code to the chip over USB
* Because this is Windows, one or more of the above installs may require a reboot.
* Open a git-bash CLI window and edit or create a file named .bashrc in your home directory ~/ and add the following text.

```bash
# SDCC compiler tools
export PATH=$PATH:/c/Program\ Files/SDCC/bin

# Mingw tools (for Make)
export PATH=$PATH:/c/MinGW/bin

alias make=mingw32-make.exe
```

* Exit out of the git-bash CLI Window and open it up again to have it load the new .bashrc file.  It may give you a message about creating other files automatically (like .profile .bashprofile etc.)
* Next we need to download some test code to test compiling from  [The 84 Badge github repository](https://github.com/gowenrw/84_Badge)
* At the git-bash CLI type the following to clone this repository:
```
git clone https://github.com/gowenrw/84_Badge.git
```

* This will create a directory named 84_Badge containing all of the files.
* Change directory to 84_Badge/code/dev/CH552G_blink/
* You should see two files there, a Makefile and a main.c file.  You should not need to modify these files if you are using an 84 Badge or its development board.
Even if you are using a different development board, we are just going to try to compile it to verify our toolchain is working.
* Type ```make``` in this directory and it should compile this example.  If it does not then read the errors to see what is wrong and try again until it compiles without error.
* Upon successful compile you will have many more files in this directory including one named blink.hex which is the file we will attempt to push to the chip

At this point your compiler toolchain is complete and verified.

Next up, USB communication to push code to the micro controller.

* If you have an 84 Badge or its development board or a different  CH55x development board you can test pushing this code to the chip using the WCHISPTOOL.  From Windows start menu launch the WCHISPTOOL.
* Next plug in the CH55x development board into a USB port in programming mode (hold down the appropriate button while inserting the USB).
* In the WCHISPTOOL Choose the tab for the chip type you have plugged in and look for your device name listed.  For the 84 Badge this will be under the 8-bit tab using the drop down to select 552G. If your chip is not listed as connected try to unplug and reconnect the chip to get it to show up.  If still having issues reinstall the WCH USB Driver (included with the tool)
* In the WCHISPTOOL chip specific tab choose the file to download to the chip.  This can be the blink.hex file you created for testing or another example.  Click the download button and it will push this file to the chip.  In the dialog box you will see its progress and completion status.

Congratulations, you have successfully downloaded the compiled firmware to the micro controller.

### Debian Linux Setup

Here are the steps I followed to get the toolchain fully set up to compile and push code to the CH55x chips on my Ubuntu (Debian based) Linux box.

* Install the compiler tool chain with the following:
```
sudo apt install build-essential sdcc
```

* Next we need to download some test code to test compiling from  [The 84 Badge github repository](https://github.com/gowenrw/84_Badge) with the following:
```
git clone https://github.com/gowenrw/84_Badge.git
```

* This will create a directory named 84_Badge containing all of the files.
* Change directory to 84_Badge/code/dev/CH552G_blink/
* You should see two files there, a Makefile and a main.c file.  You should not need to modify these files if you are using an 84 Badge or its development board.
Even if you are using a different development board, we are just going to try to compile it to verify our toolchain is working.
* Type ```make``` in this directory and it should compile this example.  If it does not then read the errors to see what is wrong and try again until it compiles without error.
* Upon successful compile you will have many more files in this directory including one named blink.hex which is the file we will attempt to push to the chip

At this point your compiler toolchain is complete and verified.

Next up, USB communication to push code to the micro controller.

* Download and install the libusb 1.0 development image with the following:
```
sudo apt-get install libusb-1.0-0-dev
```

* Download the open-source implementation of the WCH ISP Tool from here: [LibreCH551 Tool](https://github.com/rgwan/librech551) with the following:
```
git clone https://github.com/rgwan/librech551.git
```

* This will create a directory named librech551 containing all of the source files.
* Change directory to librech551/usbisp/
* You should see two files there, a Makefile and a main.c file.
* Type ```make``` in this directory and it should compile the ```wchisptool``` executable.  If it does not then read the errors to see what is wrong and try again until it compiles without error (warnings are usually ok as long as the executable is produced).
* Once you have a successful compilation type ```make install``` in order to install the program. (you might have to use ```sudo``` with this if you get a permission denied error)
* To download code to the chip use the following:
```
sudo wchisptool -f mycode.bin
```

Congratulations, you have successfully downloaded the compiled firmware to the micro controller.

NOTE: The linux wchisptool is hit or miss on working.  Have had quite a few issues with it and am looking for an alternative.

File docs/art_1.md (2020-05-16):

---
title: Art Details
parent: Art
nav_order: 1
---

# The Art of the 84 Badge - Details

Here are some additional details about the artwork for the badge.

## Files

All of the artwork files are included in the [84 Badge github repository](https://github.com/gowenrw/84_Badge) including the Adobe Illustrator files, inspiration images and fonts.

Here are a few quick links
*  [My final Adobe Illustrator file](https://github.com/gowenrw/84_Badge/blob/master/art/84_Badge_Silk_05.ai)
*  [A JPG export from the AI file above](https://github.com/gowenrw/84_Badge/blob/master/art/84_Badge_Silk_05_without_edges.jpg)
*  [3000 Society Con Poster using this art](https://github.com/gowenrw/84_Badge/blob/master/art/3000_Society_Con_Poster.jpg)

## Wonder Woman Sketch

After finding the perfect image of Wonder Woman with her lasso to use on the badge I had to sketch it all out in AI to make it all one color.  
This was difficult given all the shading and solid areas.
I used a combination of cross hatch patterns and dots to perform the shading affects I wanted using just one color.

WW_Sketch

## Terminator Sketch

For the Terminator I couldn't find a single image that portrayed him the way I wanted, which was half Arnold Schwarzenegger and half robot skeleton as the humanoid portion was being blasted away.
So I based it off of a couple of different images to create the Terminator I wanted.
Once again I had to use patterns to provide the shading effects in one color.

WW_Sketch

## Last Starfighter Gunstar Sketch

For the Last Starfighters Gunstar there were literally dozens of images that could have worked.
The one that I based my sketch from had nice crisp lines (minimizing the pattern shading I would have to do) and it clearly showed the Star League markings.

Gunstar_Sketch

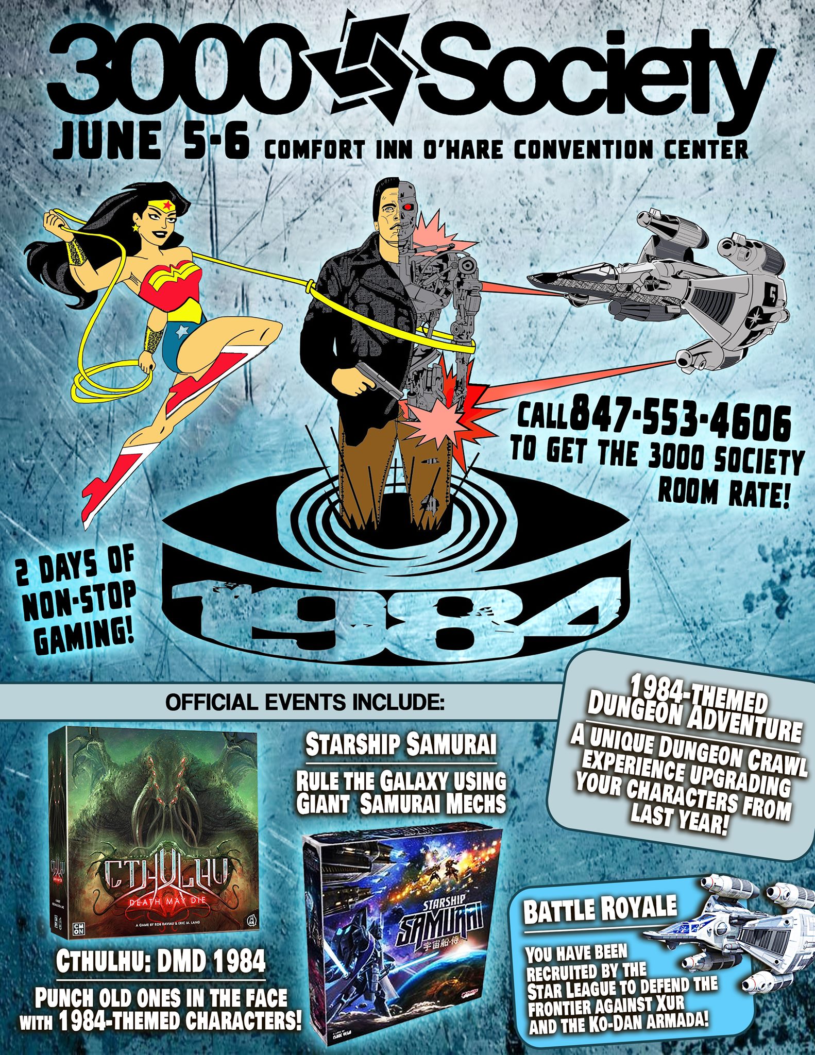
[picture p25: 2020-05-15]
art/3000_Society_Con_Poster.jpg

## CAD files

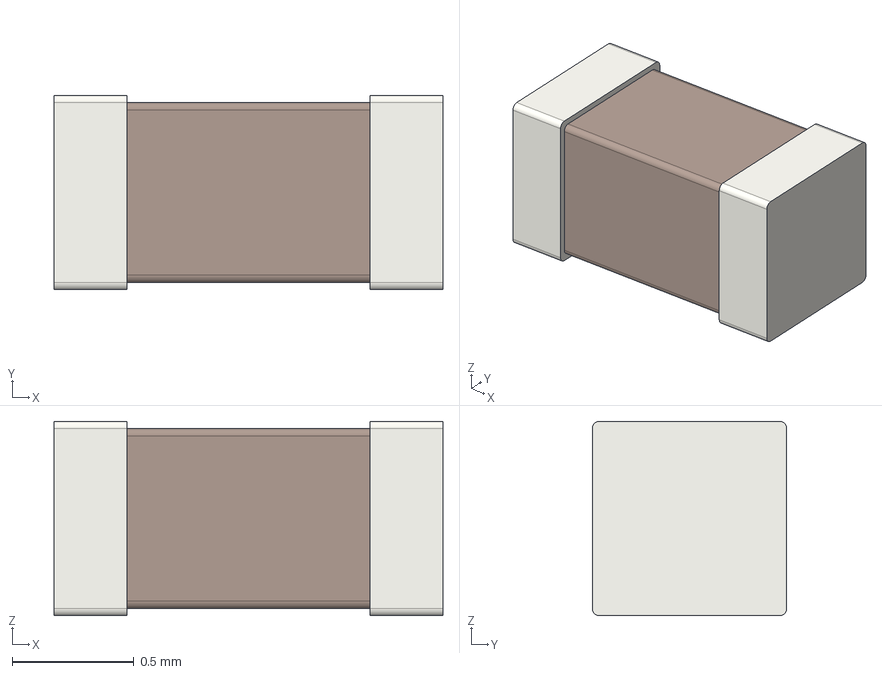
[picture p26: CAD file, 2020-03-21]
eda/dev/3d_models/C_0603_1608Metric.step
1.60 x 0.8 x 0.8 mm

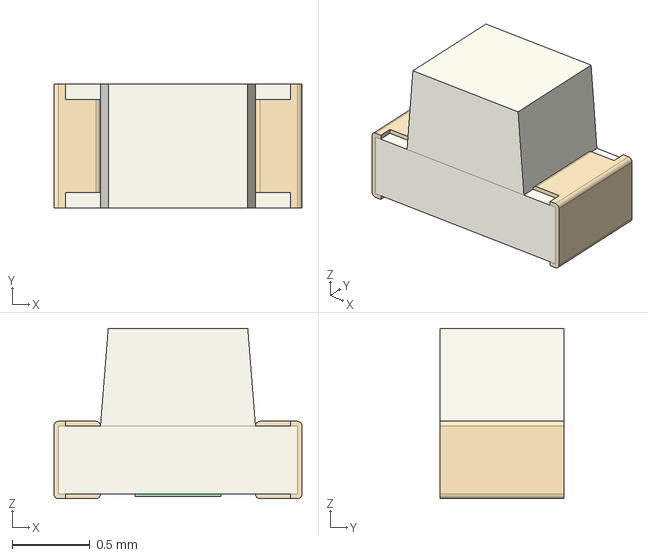
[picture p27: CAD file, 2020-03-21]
eda/prod/3d_models/LED_0603_1608Metric.step
1.60 x 0.8 x 1.10 mm

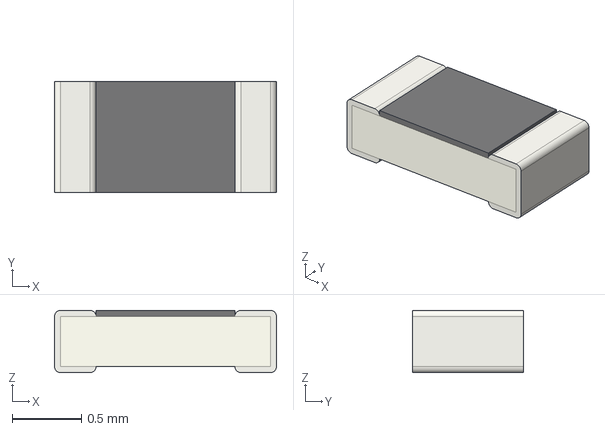
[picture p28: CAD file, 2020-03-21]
eda/dev/3d_models/R_0603_1608Metric.step
1.60 x 0.8 x 0.45 mm

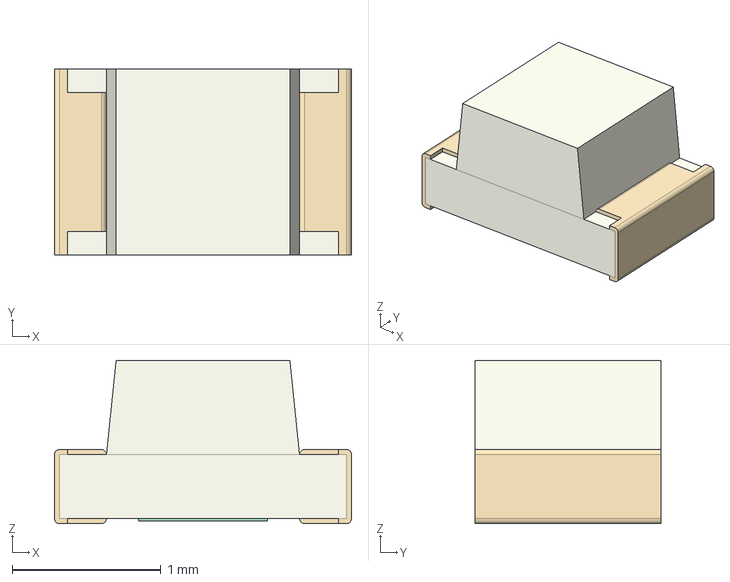
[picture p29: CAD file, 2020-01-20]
eda/dev/3d_models/LED_0805_2012Metric.step
2.00 x 1.25 x 1.10 mm

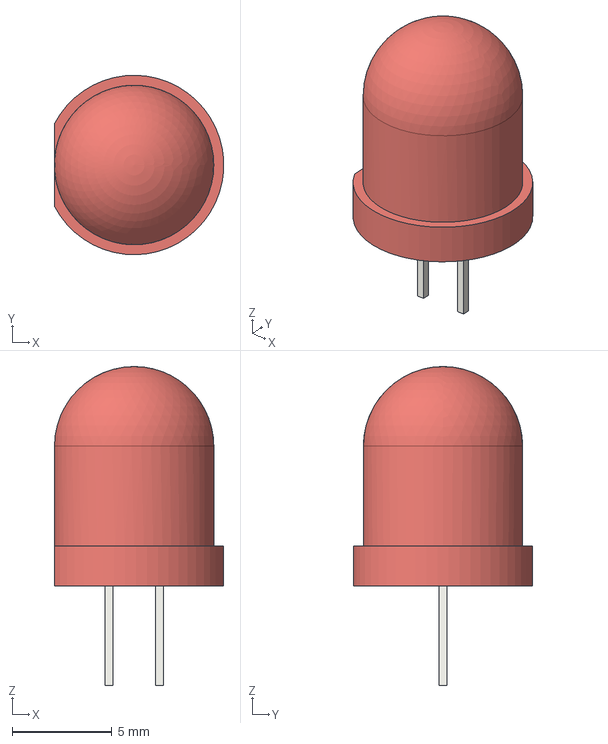
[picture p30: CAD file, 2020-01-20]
eda/prod/3d_models/LED_D8.0mm.step
8.49 x 9.00 x 16.0 mm

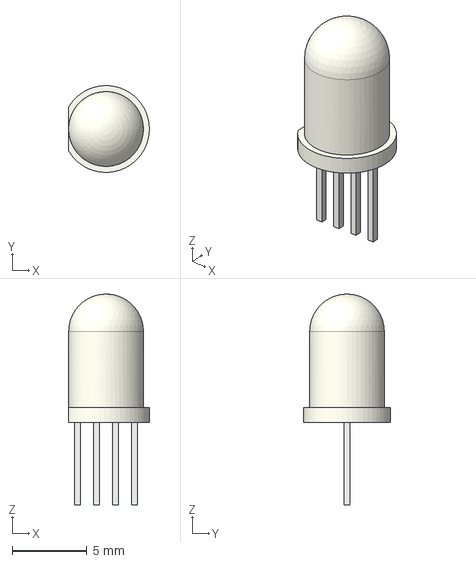
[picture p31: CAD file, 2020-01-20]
eda/dev/3d_models/LED_D5.0mm-4_RGB_Neo.step
5.40 x 5.79 x 14.1 mm

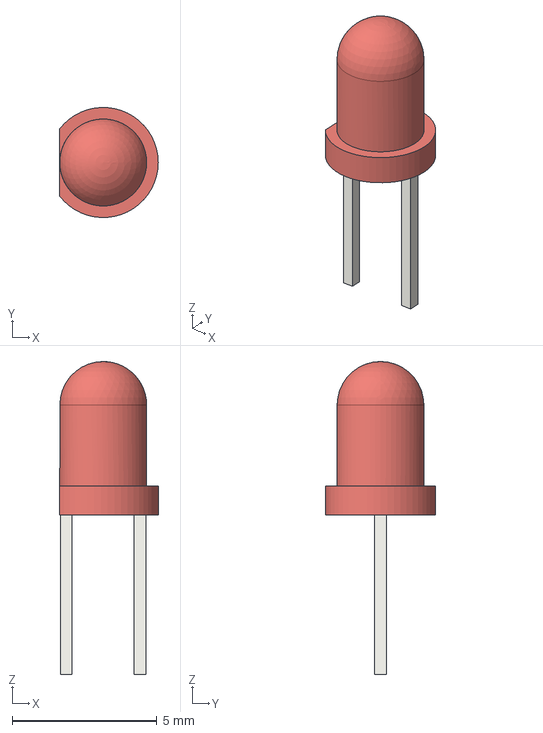
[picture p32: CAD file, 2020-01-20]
eda/prod/3d_models/LED_D3.0mm.step
3.40 x 3.80 x 10.8 mm

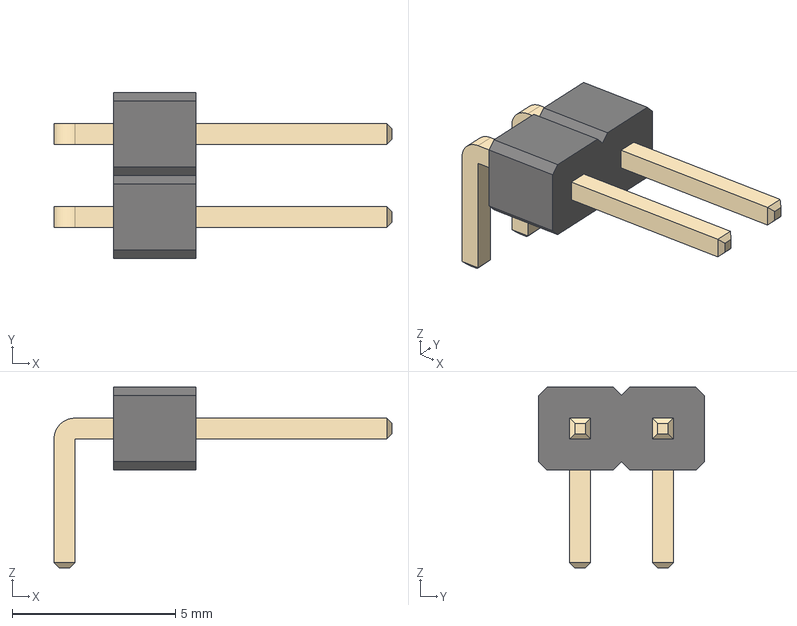
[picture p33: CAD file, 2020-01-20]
eda/dev/3d_models/PinHeader_1x02_P2.54mm_Horizontal.step
10.4 x 5.08 x 5.54 mm

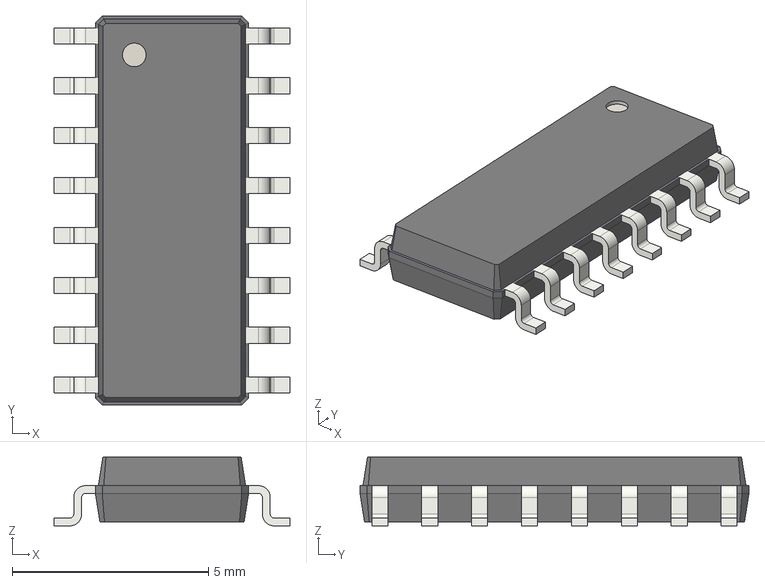
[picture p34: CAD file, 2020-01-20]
eda/prod/3d_models/SOIC-16_3.9x9.9mm_P1.27mm.step
6.00 x 9.90 x 1.75 mm

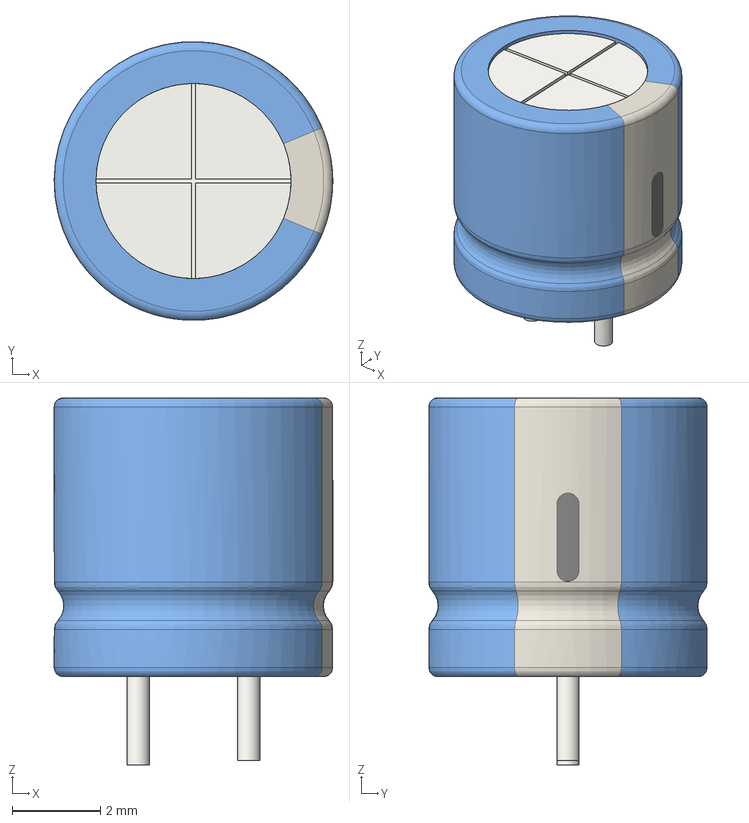
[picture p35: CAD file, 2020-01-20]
eda/dev/3d_models/CP_Radial_D6.3mm_P2.50mm.step
6.30 x 6.30 x 8.30 mm

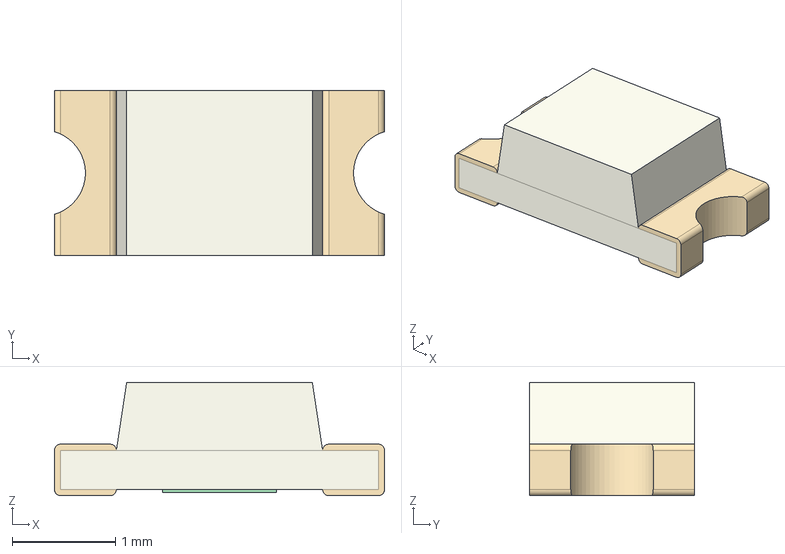
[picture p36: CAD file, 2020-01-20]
eda/prod/3d_models/LED_1206_3216Metric_Castellated.step
3.20 x 1.60 x 1.10 mm

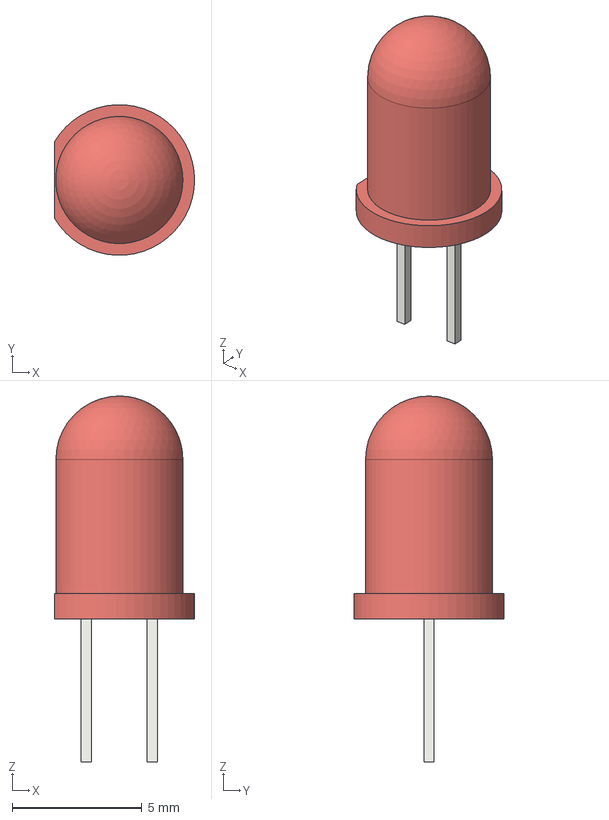
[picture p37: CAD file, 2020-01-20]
eda/dev/3d_models/LED_D5.0mm.step
5.40 x 5.79 x 14.1 mm

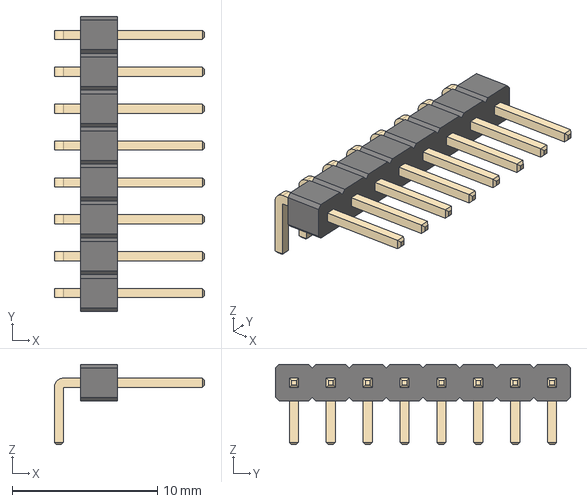
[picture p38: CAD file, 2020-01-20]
eda/prod/3d_models/PinHeader_1x08_P2.54mm_Horizontal.step
10.4 x 20.3 x 5.54 mm

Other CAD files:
eda/prod/3d_models/LED_0603_1608Metric_Castellated.step
eda/dev/3d_models/LED_0603_1608Metric_Castellated.step
eda/dev/3d_models/Battery_Holder_3xAAA_Simple.step
eda/dev/3d_models/C_0805_2012Metric.step
eda/dev/3d_models/C_1206_3216Metric.step
eda/dev/3d_models/C_Disc_D3.0mm_W2.0mm_P2.50mm.step
eda/dev/3d_models/C_Rect_L4.6mm_W2.0mm_P2.50mm_MKS02_FKP02.step
eda/dev/3d_models/LED_0805_2012Metric_Castellated.step
eda/dev/3d_models/LED_1206_3216Metric.step
eda/dev/3d_models/PinHeader_1x02_P2.54mm_Vertical.step
eda/dev/3d_models/PinHeader_1x08_P2.54mm_Vertical.step
eda/dev/3d_models/RJ45_Amphenol_RJHSE-5080-56544.STEP
eda/dev/3d_models/RJ45_Amphenol_RJHSE538X.step
eda/dev/3d_models/R_0805_2012Metric.step
eda/dev/3d_models/R_1206_3216Metric.step
eda/dev/3d_models/R_Axial_DIN0204_L3.6mm_D1.6mm_P5.08mm_Horizontal.step
eda/dev/3d_models/R_Axial_DIN0207_L6.3mm_D2.5mm_P7.62mm_Horizontal.step
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

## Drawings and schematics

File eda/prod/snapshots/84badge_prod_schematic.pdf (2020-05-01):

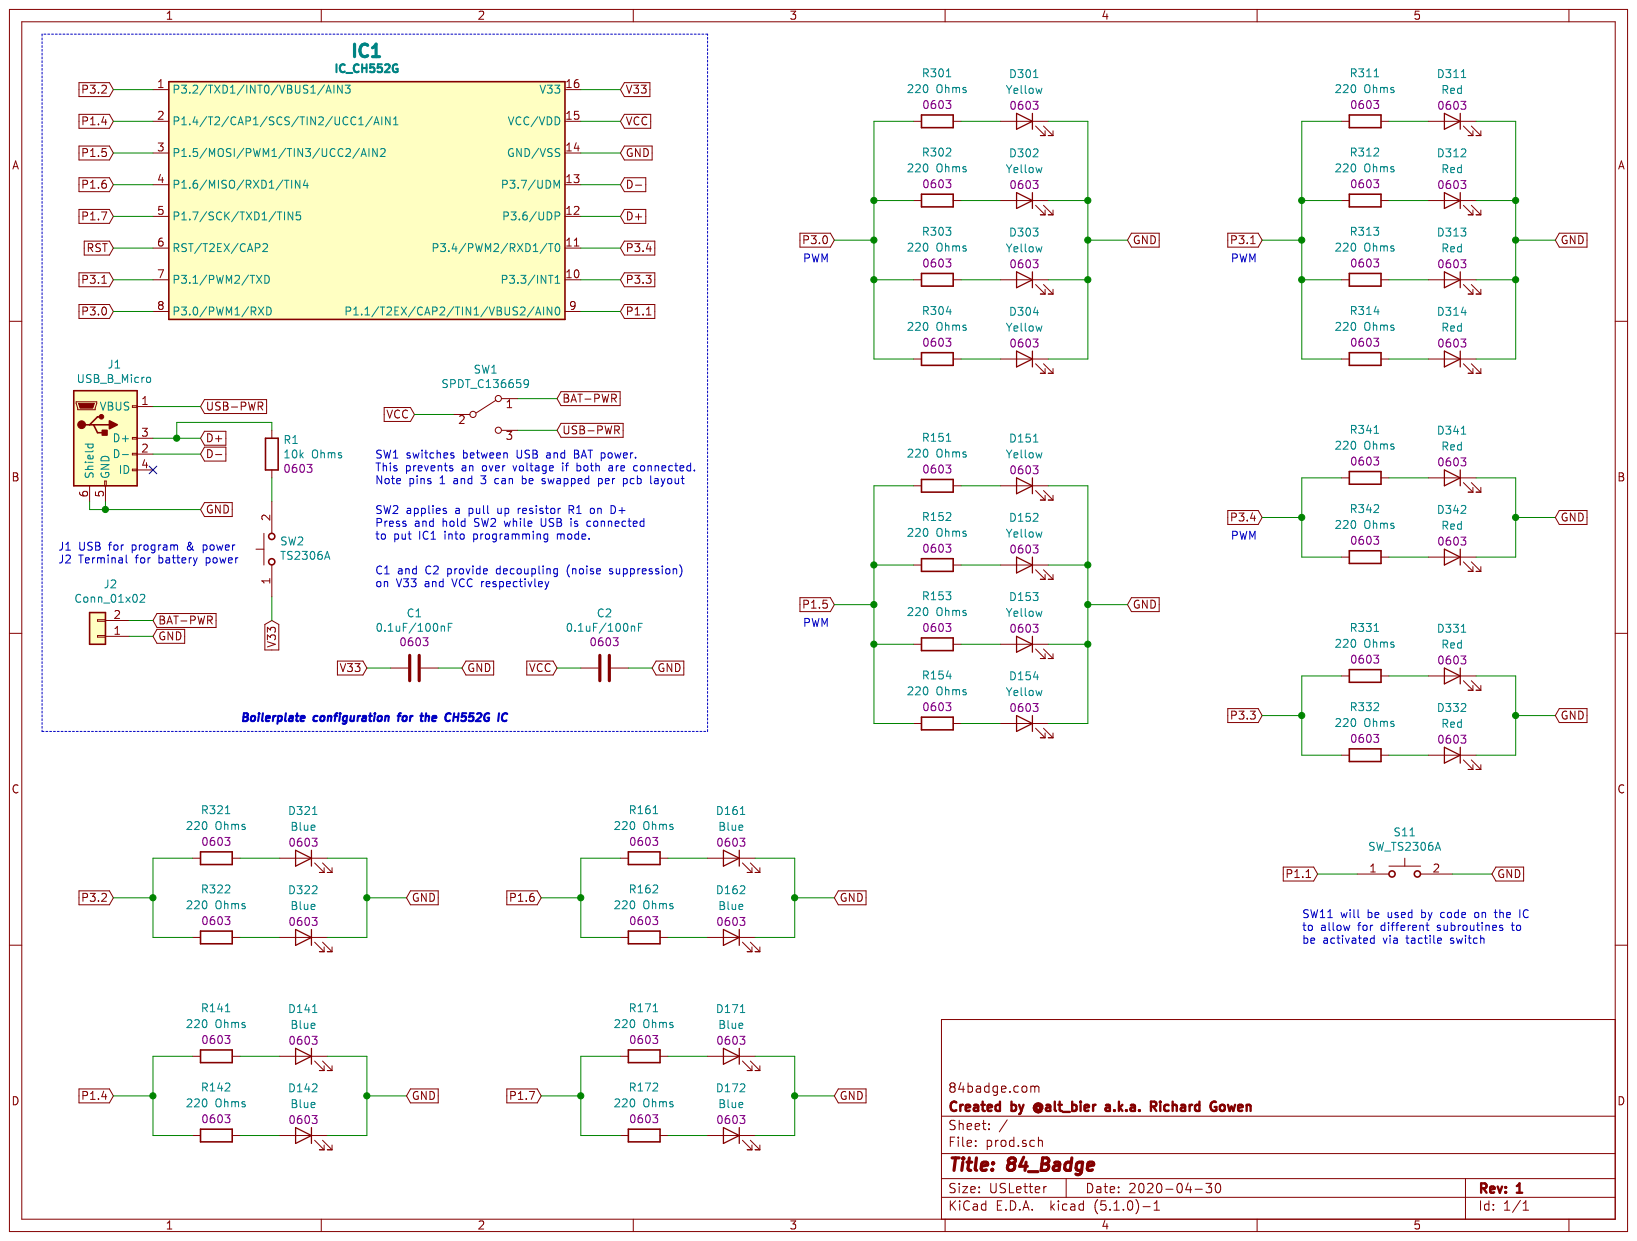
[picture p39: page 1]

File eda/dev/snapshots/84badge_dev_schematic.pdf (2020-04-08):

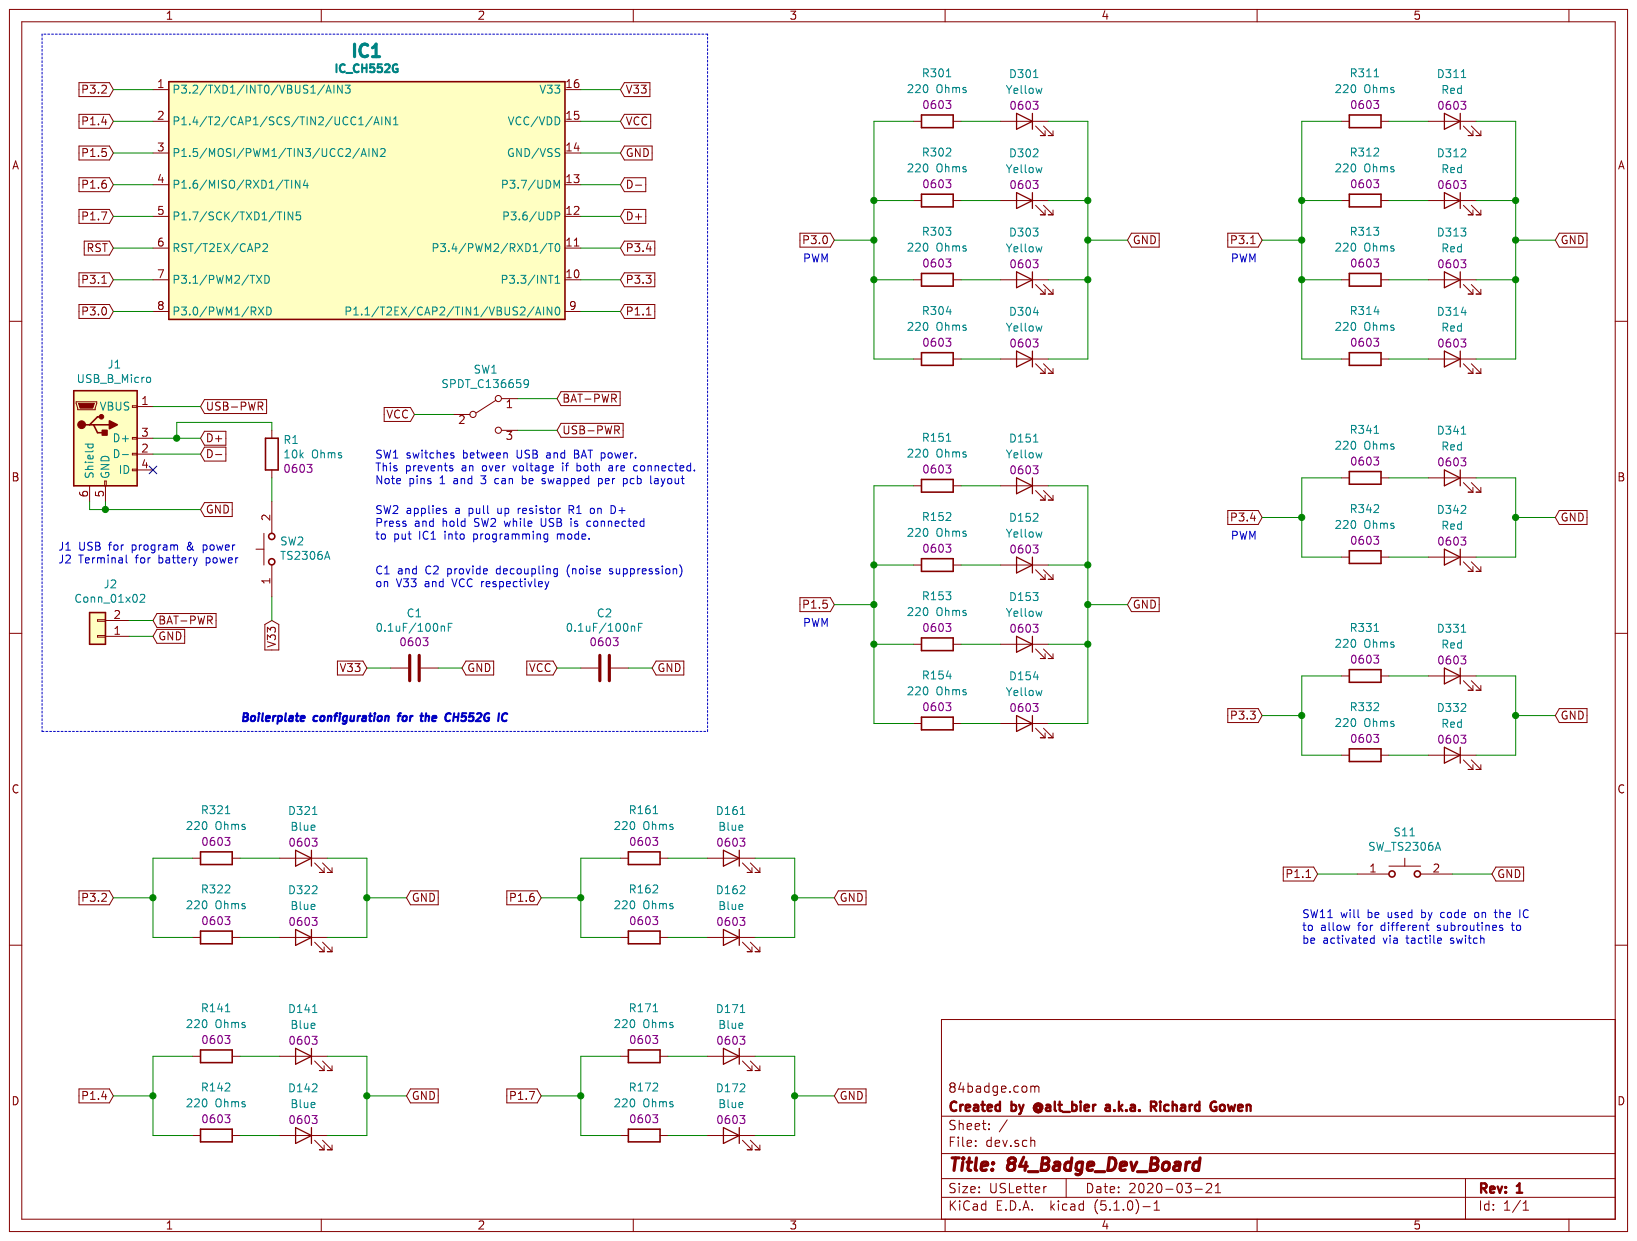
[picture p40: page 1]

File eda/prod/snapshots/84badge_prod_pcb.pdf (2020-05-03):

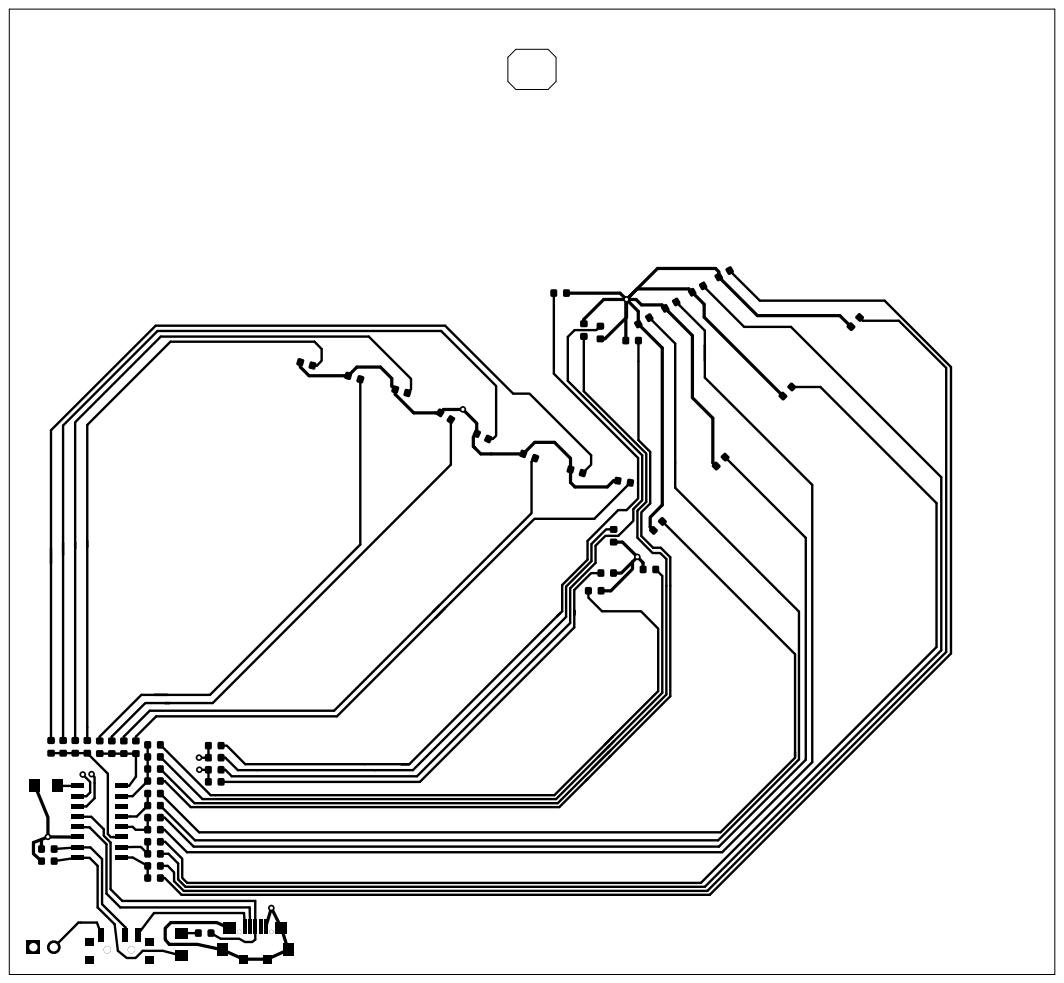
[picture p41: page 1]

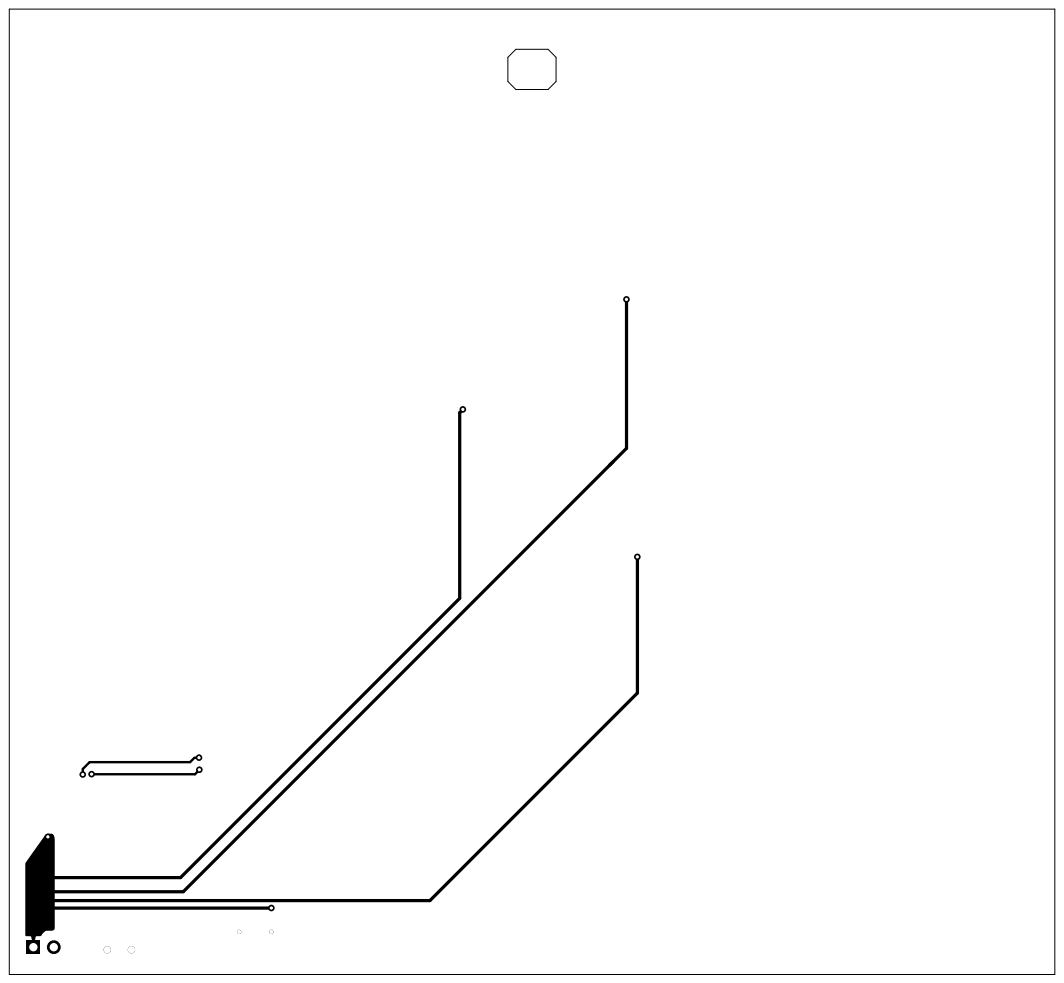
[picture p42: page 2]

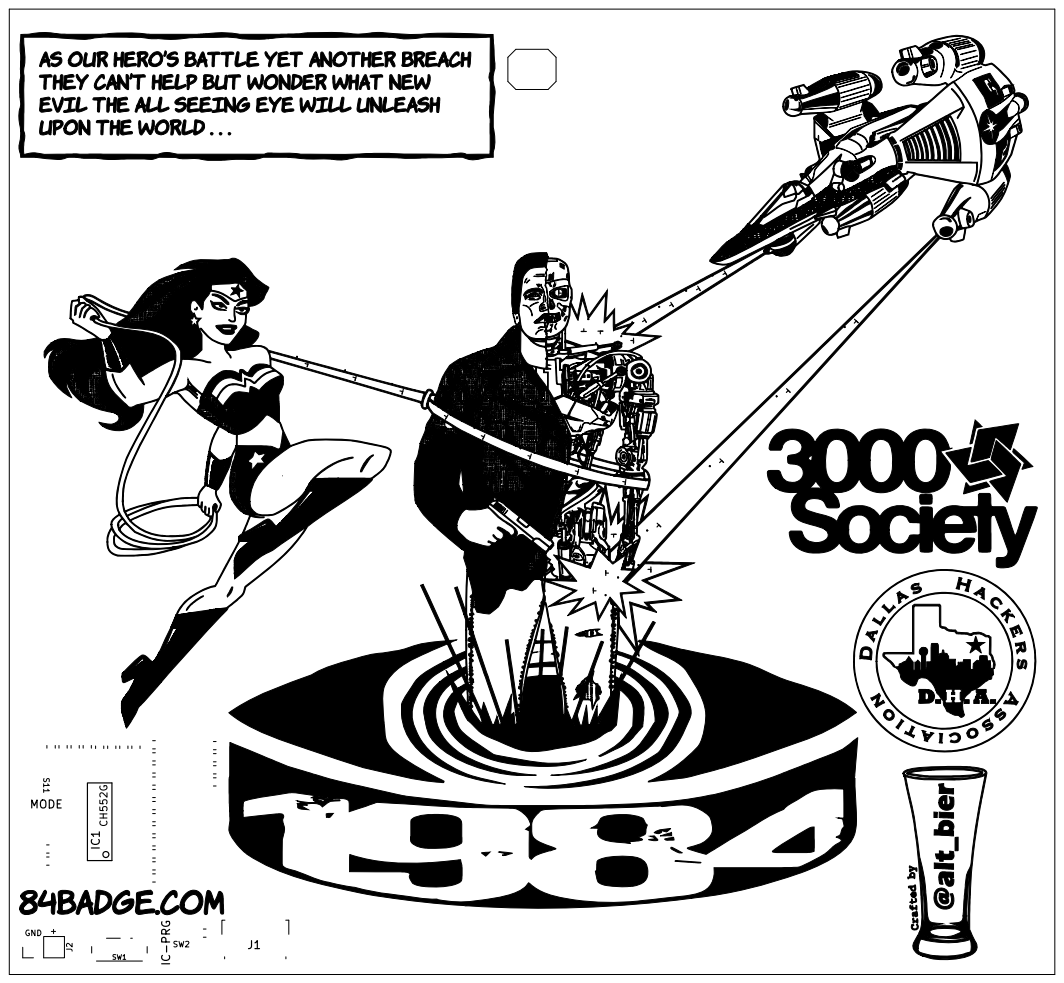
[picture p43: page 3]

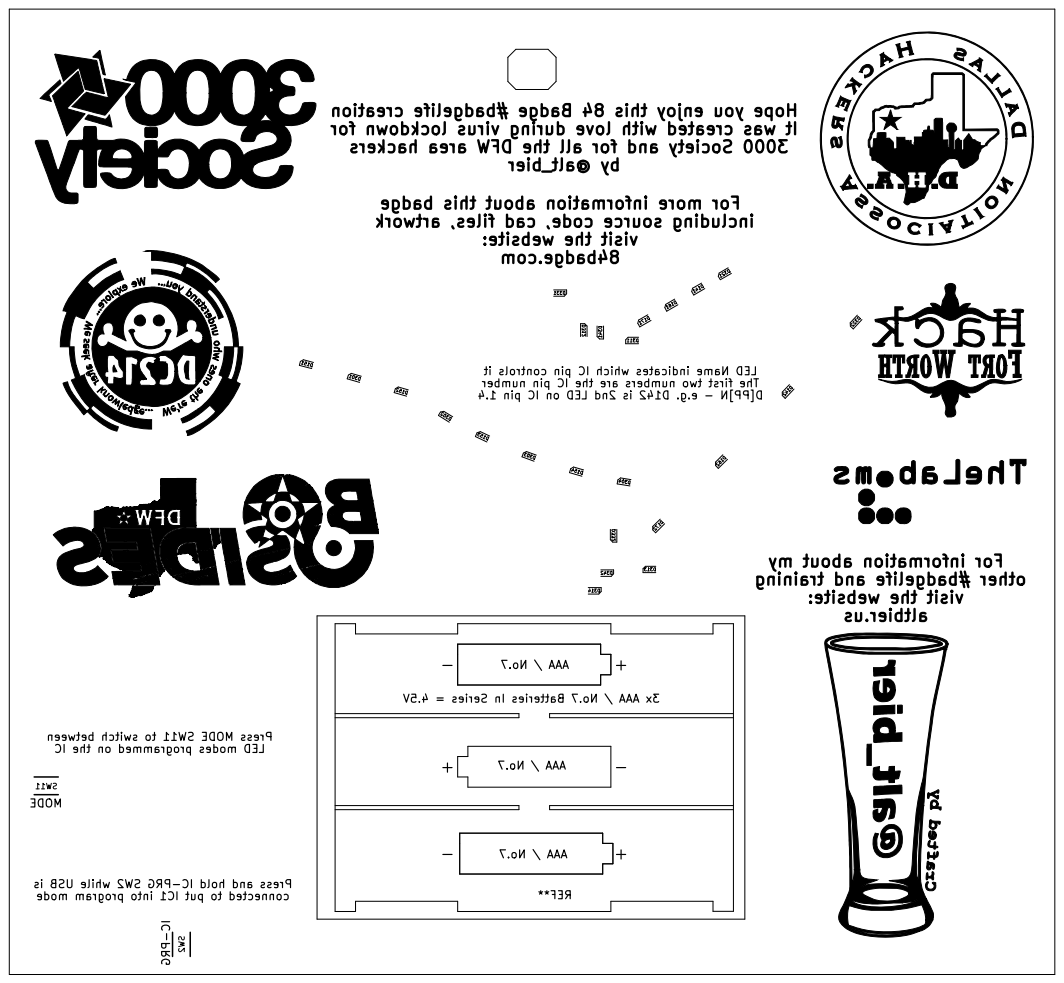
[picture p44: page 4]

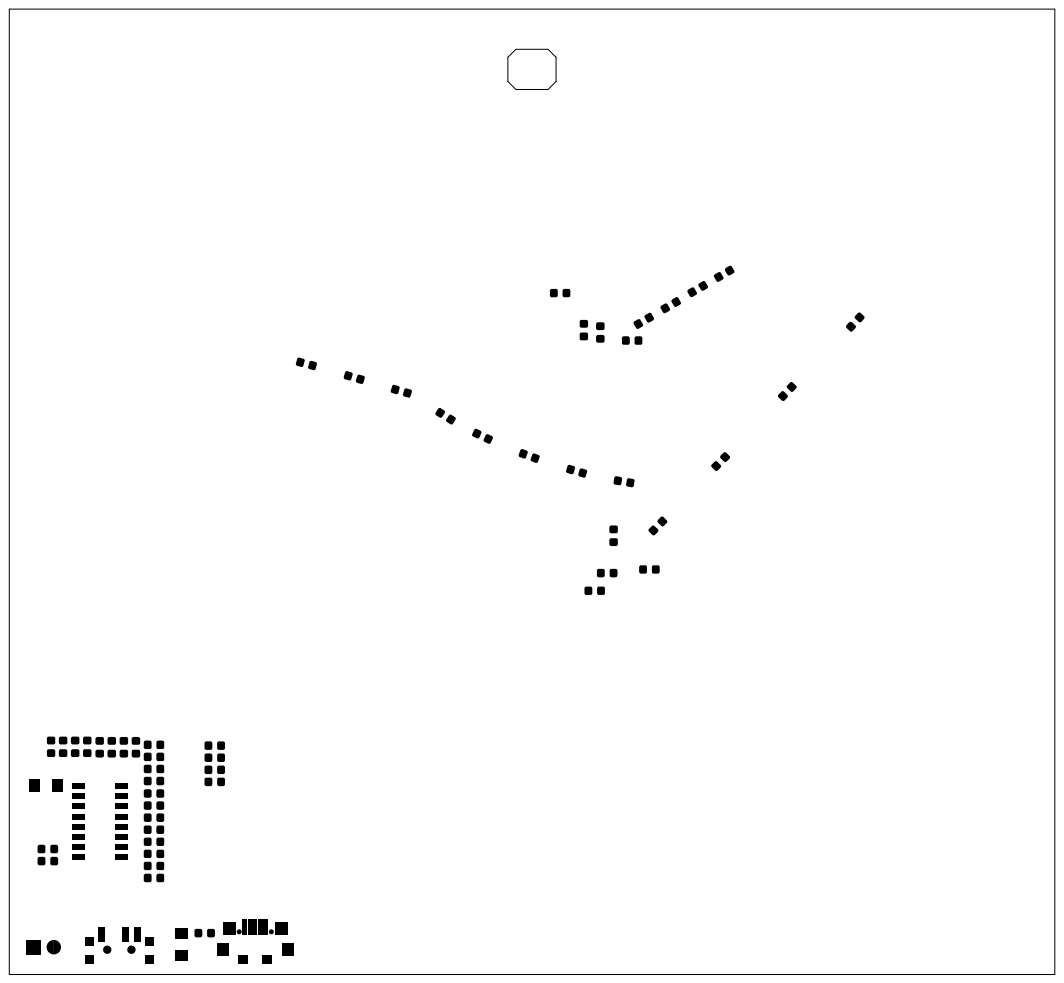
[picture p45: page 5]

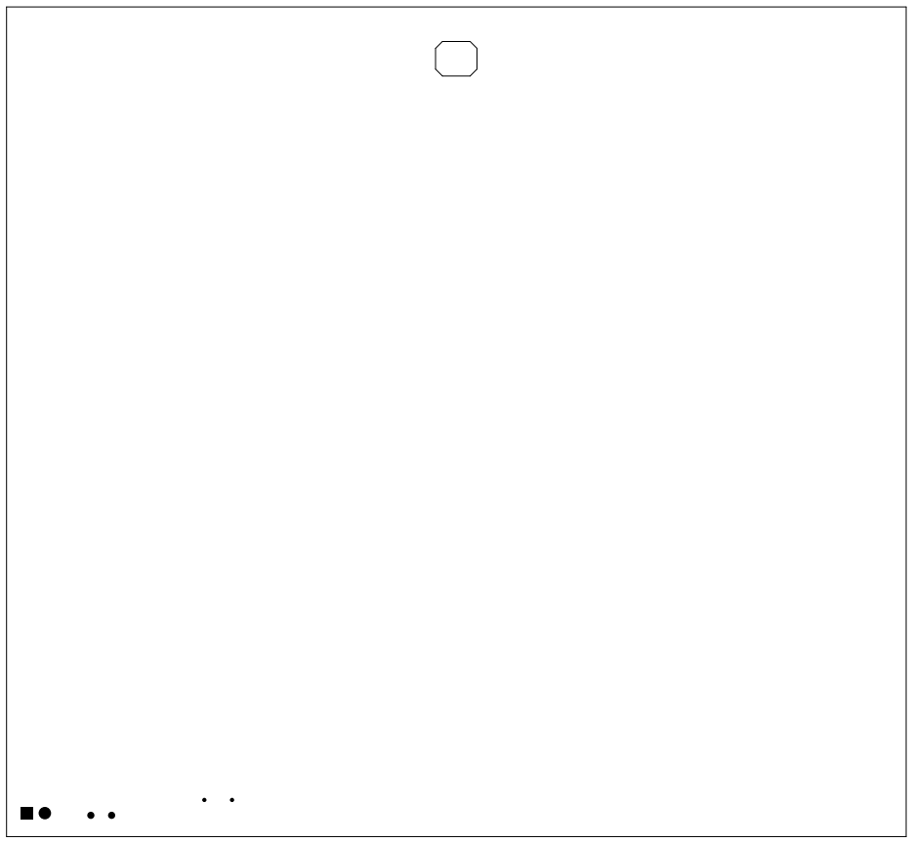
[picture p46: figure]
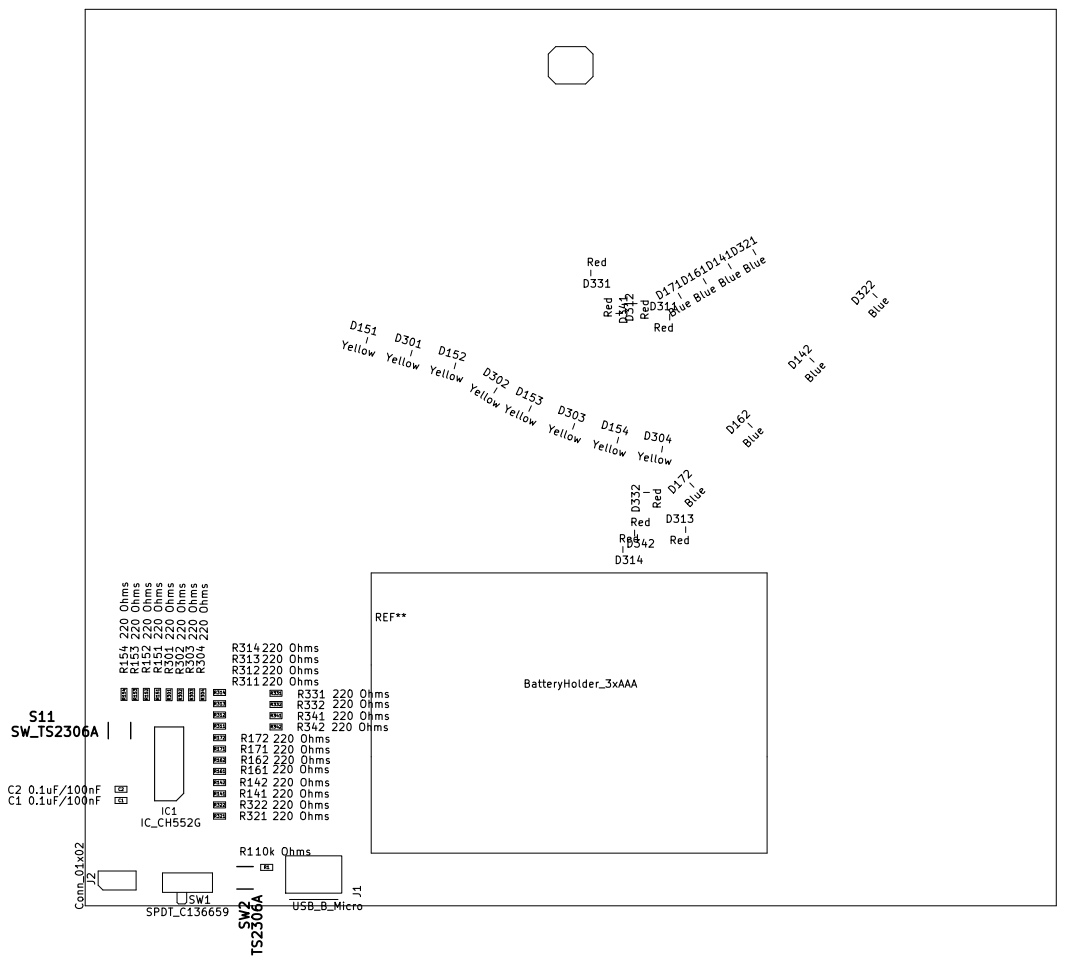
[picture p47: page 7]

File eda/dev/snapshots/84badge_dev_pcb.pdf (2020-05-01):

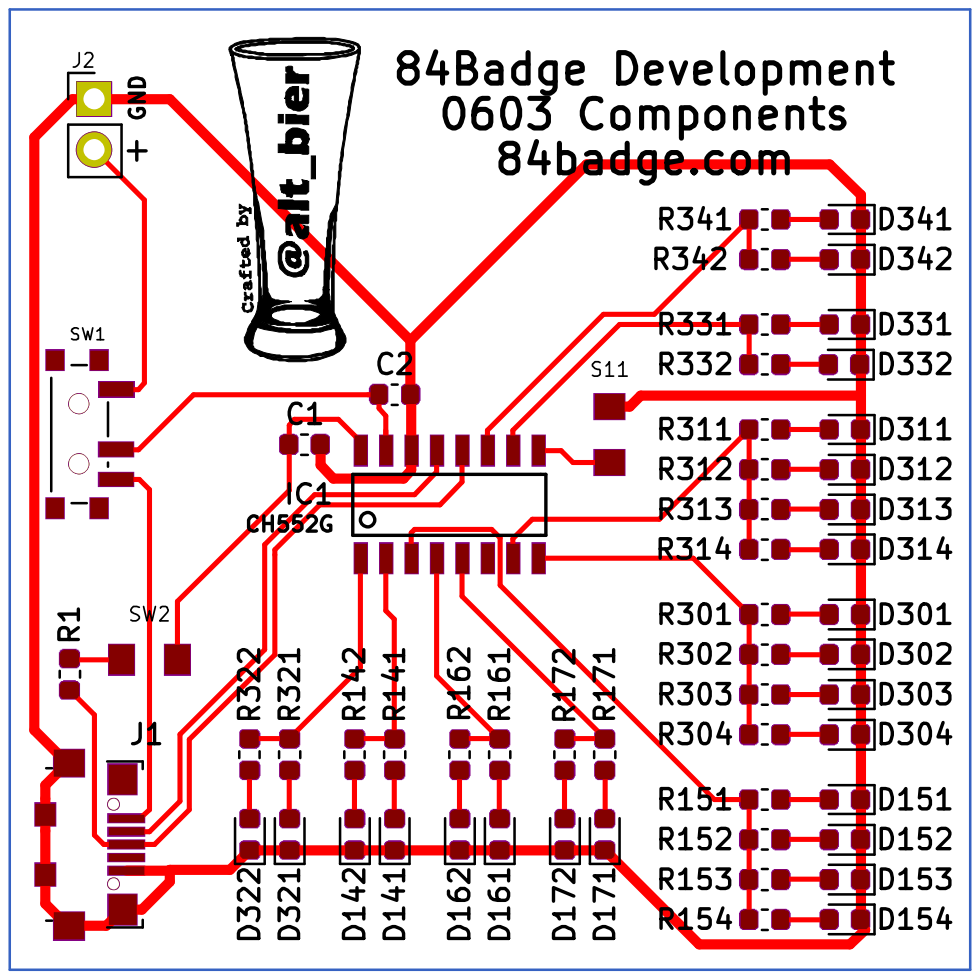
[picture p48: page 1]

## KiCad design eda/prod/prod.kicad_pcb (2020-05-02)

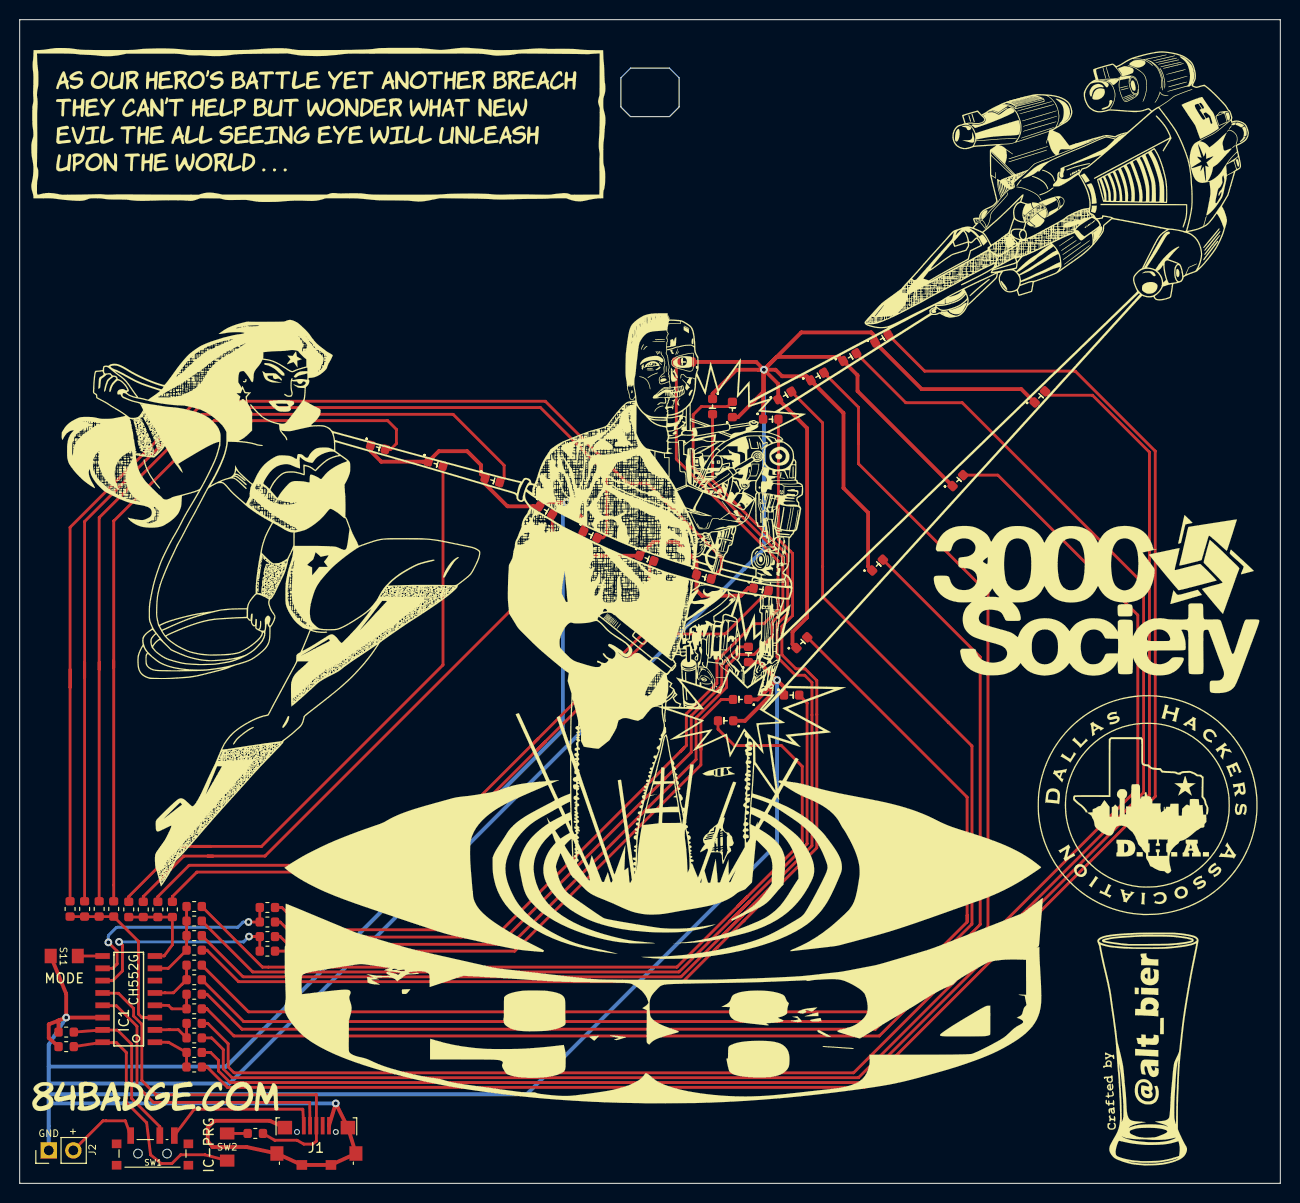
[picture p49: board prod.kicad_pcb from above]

Board: 2 copper layers, 130.0 x 120.0 mm, 57 parts (0 on the bottom side), 42 nets.

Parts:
C1, C2: 0.1uF/100nF; C_0603_1608Metric
D141, D142, D161, D162, D171, D172, D321, D322: Blue; LED_0603_1608Metric_lowsilk
D151, D152, D153, D154, D301, D302, D303, D304: Yellow; LED_0603_1608Metric_lowsilk
D311, D312, D313, D314, D331, D332, D341, D342: Red; LED_0603_1608Metric_lowsilk
IC1: IC_CH552G; IC_SOIC-16_3.9x9.9mm_Pitch1.27mm
J1: USB_B_Micro; USB_Micro-B_Jing
J2: Conn_01x02; Conn_Pin_Header_Straight_1x02_Pitch2.54mm
R1: 10k Ohms; R_0603_1608Metric
R141, R142, R151, R152, R153, R154, R161, R162, R171, R172, R301, R302, R303, R304, R311, R312, R313, R314, R321, R322, R331, R332, R341, R342: 220 Ohms; R_0603_1608Metric
S11: SW_TS2306A; SW_TS2306A240GFMSM9_C388290
SW1: SPDT_C136659; SW_SPDT_PCM12_C136659
SW2: TS2306A; SW_TS2306A240GFMSM9_C388290

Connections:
BAT-PWR: J2.2, SW1.1
D+: IC1.12, J1.3, R1.1
D-: IC1.13, J1.2
GND: C1.2, C2.2, D141.1, D142.1, D151.1, D152.1, D153.1, D154.1, D161.1, D162.1, D171.1, D172.1, D301.1, D302.1, D303.1, D304.1, D311.1, D312.1, D313.1, D314.1, D321.1, D322.1, D331.1, D332.1, D341.1, D342.1, IC1.14, J1.5, J1.6, J2.1, S11.2
unnamed: D141.2, R141.2
unnamed: D142.2, R142.2
unnamed: D151.2, R151.2
unnamed: D152.2, R152.2
unnamed: D153.2, R153.2
unnamed: D154.2, R154.2
unnamed: D161.2, R161.2
unnamed: D162.2, R162.2
unnamed: D171.2, R171.2
unnamed: D172.2, R172.2
unnamed: D301.2, R301.2
unnamed: D302.2, R302.2
unnamed: D303.2, R303.2
unnamed: D304.2, R304.2
unnamed: D311.2, R311.2
unnamed: D312.2, R312.2
unnamed: D313.2, R313.2
unnamed: D314.2, R314.2
unnamed: D321.2, R321.2
unnamed: D322.2, R322.2
unnamed: D331.2, R331.2
unnamed: D332.2, R332.2
unnamed: D341.2, R341.2
unnamed: D342.2, R342.2
unnamed: R1.2, SW2.2
P1.1: IC1.9, S11.1
P1.4: IC1.2, R141.1, R142.1
P1.5: IC1.3, R151.1, R152.1, R153.1, R154.1
P1.6: IC1.4, R161.1, R162.1
P1.7: IC1.5, R171.1, R172.1
P3.0: IC1.8, R301.1, R302.1, R303.1, R304.1
P3.1: IC1.7, R311.1, R312.1, R313.1, R314.1
P3.2: IC1.1, R321.1, R322.1
P3.3: IC1.10, R331.1, R332.1
P3.4: IC1.11, R341.1, R342.1
USB-PWR: J1.1, SW1.3
V33: C1.1, IC1.16, SW2.1
VCC: C2.1, IC1.15, SW1.2

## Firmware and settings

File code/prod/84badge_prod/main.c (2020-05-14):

// 84 Badge
// This is the main production code for the badge

#include <ch554.h>
#include <debug.h>

// define the sub-pins for pin 3
#define LEDY30_PIN 0
#define LEDR31_PIN 1
#define LEDB32_PIN 2
#define LEDR33_PIN 3
#define LEDR34_PIN 4
// define the sub-pins for pin 1
#define BUTTON11_PIN 1
#define LEDB14_PIN 4
#define LEDY15_PIN 5
#define LEDB16_PIN 6
#define LEDB17_PIN 7

// assign sub-pins to pins
// P1 = 0x90 P3 = 0xB0
SBIT(LEDY30, 0xB0, LEDY30_PIN);
SBIT(LEDR31, 0xB0, LEDR31_PIN);
SBIT(LEDB32, 0xB0, LEDB32_PIN);
SBIT(LEDR33, 0xB0, LEDR33_PIN);
SBIT(LEDR34, 0xB0, LEDR34_PIN);
SBIT(BUTTON11, 0x90, BUTTON11_PIN);
SBIT(LEDB14, 0x90, LEDB14_PIN);
SBIT(LEDY15, 0x90, LEDY15_PIN);
SBIT(LEDB16, 0x90, LEDB16_PIN);
SBIT(LEDB17, 0x90, LEDB17_PIN);

// 1 byte integer for putton push flag - no bool type available
uint8_t button11push=0;

// 1 byte integer for LED Mode (controlled by button)
// Modes 1 is the default start mode
uint8_t ledmode=1;

void main() {
    CfgFsys();

    // setup pin 3
    // Configure pin 3.0 as GPIO output
    P3_MOD_OC = P3_MOD_OC & ~(1<<LEDY30_PIN);
    P3_DIR_PU = P3_DIR_PU |	(1<<LEDY30_PIN);
    // Configure pin 3.1 as GPIO output
    P3_MOD_OC = P3_MOD_OC & ~(1<<LEDR31_PIN);
    P3_DIR_PU = P3_DIR_PU |	(1<<LEDR31_PIN);
    // Configure pin 3.2 as GPIO output
    P3_MOD_OC = P3_MOD_OC & ~(1<<LEDB32_PIN);
    P3_DIR_PU = P3_DIR_PU |	(1<<LEDB32_PIN);
    // Configure pin 3.3 as GPIO output
    P3_MOD_OC = P3_MOD_OC & ~(1<<LEDR33_PIN);
    P3_DIR_PU = P3_DIR_PU |	(1<<LEDR33_PIN);
    // Configure pin 3.4 as GPIO output
    P3_MOD_OC = P3_MOD_OC & ~(1<<LEDR34_PIN);
    P3_DIR_PU = P3_DIR_PU |	(1<<LEDR34_PIN);

    // setup pin 1
    // Configure pin 1.4 as GPIO output
    P1_MOD_OC = P1_MOD_OC & ~(1<<LEDB14_PIN);
    P1_DIR_PU = P1_DIR_PU |	(1<<LEDB14_PIN);
    // Configure pin 1.5 as GPIO output
    P1_MOD_OC = P1_MOD_OC & ~(1<<LEDY15_PIN);
    P1_DIR_PU = P1_DIR_PU |	(1<<LEDY15_PIN);
    // Configure pin 1.6 as GPIO output
    P1_MOD_OC = P1_MOD_OC & ~(1<<LEDB16_PIN);
    P1_DIR_PU = P1_DIR_PU |	(1<<LEDB16_PIN);
    // Configure pin 1.7 as GPIO output
    P1_MOD_OC = P1_MOD_OC & ~(1<<LEDB17_PIN);
    P1_DIR_PU = P1_DIR_PU |	(1<<LEDB17_PIN);

    // Setting all LEDs to off at start
    LEDY30 = 0;
    LEDY15 = 0;
    LEDR31 = 0;
    LEDR33 = 0;
    LEDR34 = 0;
    LEDB32 = 0;
    LEDB14 = 0;
    LEDB16 = 0;
    LEDB17 = 0;

    // ********************************
    // ********* Primary Loop *********
    // ********************************
    while (1) {
        // ********************************
        // ********** LED MODE 3 **********
        // ********************************
        if (ledmode == 3) {
          // *****
          // ***** This mode keeps all LEDs ON
          // *****
          // Delay to display previous LED state
          mDelaymS(300);
          // If we see button push set button push flag
          if (BUTTON11 == 0) { button11push = 1; }
          // ***** Set LED states to on or off
          LEDY30 = 1, LEDY15 = 1, LEDR31 = 1, LEDR33 = 1, LEDR34 = 1, LEDB32 = 1, LEDB14 = 1, LEDB16 = 1, LEDB17 = 1;
          // ***** End of this LED mode
        }
        // ********************************
        // ********** LED MODE 2 **********
        // ********************************
        if (ledmode == 2) {
          // *****
          // ***** This mode blinks LEDs in color groups
          // *****
          // Delay to display previous LED state
          mDelaymS(300);
          // If we see button push set button push flag
          if (BUTTON11 == 0) { button11push = 1; }
          // ***** Set LED states to on or off
          LEDY30 = 1, LEDY15 = 1, LEDR31 = 0, LEDR33 = 0, LEDR34 = 0, LEDB32 = 0, LEDB14 = 0, LEDB16 = 0, LEDB17 = 0;
          // Delay to display previous LED state
          mDelaymS(300);
          // If we see button push set button push flag
          if (BUTTON11 == 0) { button11push = 1; }
          // ***** Set LED states to on or off
          LEDY30 = 0, LEDY15 = 0, LEDR31 = 1, LEDR33 = 1, LEDR34 = 1, LEDB32 = 0, LEDB14 = 0, LEDB16 = 0, LEDB17 = 0;
          // Delay to display previous LED state
          mDelaymS(300);
          // If we see button push set button push flag
          if (BUTTON11 == 0) { button11push = 1; }
          // ***** Set LED states to on or off
          LEDY30 = 0, LEDY15 = 0, LEDR31 = 0, LEDR33 = 0, LEDR34 = 0, LEDB32 = 1, LEDB14 = 1, LEDB16 = 1, LEDB17 = 1;
          // ***** End of this LED mode
        }
        // ********************************
        // ********** LED MODE 1 **********
        // ********************************
        if (ledmode == 1) {
          // *****
          // ***** This mode is the LED artwork mode
          // ***** It should alternate Yellow LEDs on the lasso for a glow effect
          // ***** It should chase Blue LEDs on the lazers for a shooting effect
          // ***** It should use Red LEDs on the eye and explosions as lazers hit
          // *****
          // Delay to display previous LED state
          mDelaymS(70);
          // If we see button push set button push flag
          if (BUTTON11 == 0) { button11push = 1; }
          // ***** Set LED states to on or off
          LEDY15 = 1, LEDY30 = 1, LEDR33 = 1, LEDR34 = 0, LEDR31 = 0, LEDB32 = 0, LEDB14 = 0, LEDB16 = 0, LEDB17 = 0;
          // Delay to display previous LED state
          mDelaymS(70);
          // If we see button push set button push flag
          if (BUTTON11 == 0) { button11push = 1; }
          // ***** Set LED states to on or off
          LEDY15 = 1, LEDY30 = 1, LEDR33 = 1, LEDR34 = 0, LEDR31 = 0, LEDB32 = 0, LEDB14 = 0, LEDB16 = 0, LEDB17 = 0;
          // Delay to display previous LED state
          mDelaymS(70);
          // If we see button push set button push flag
          if (BUTTON11 == 0) { button11push = 1; }
          // ***** Set LED states to on or off
          LEDY15 = 1, LEDY30 = 1, LEDR33 = 1, LEDR34 = 0, LEDR31 = 0, LEDB32 = 0, LEDB14 = 0, LEDB16 = 0, LEDB17 = 0;
          // Delay to display previous LED state
          mDelaymS(70);
          // If we see button push set button push flag
          if (BUTTON11 == 0) { button11push = 1; }
          // ***** Set LED states to on or off
          LEDY15 = 1, LEDY30 = 1, LEDR33 = 1, LEDR34 = 0, LEDR31 = 0, LEDB32 = 0, LEDB14 = 0, LEDB16 = 0, LEDB17 = 0;
          // Delay to display previous LED state
          mDelaymS(70);
          // If we see button push set button push flag
          if (BUTTON11 == 0) { button11push = 1; }
          // ***** Set LED states to on or off
          LEDY15 = 1, LEDY30 = 1, LEDR33 = 1, LEDR34 = 0, LEDR31 = 0, LEDB32 = 0, LEDB14 = 0, LEDB16 = 0, LEDB17 = 0;
          // Delay to display previous LED state
          mDelaymS(70);
          // If we see button push set button push flag
          if (BUTTON11 == 0) { button11push = 1; }
          // ***** Set LED states to on or off
          LEDY15 = 0, LEDY30 = 1, LEDR33 = 1, LEDR34 = 0, LEDR31 = 0, LEDB32 = 0, LEDB14 = 0, LEDB16 = 0, LEDB17 = 0;
          // Delay to display previous LED state
          mDelaymS(70);
          // If we see button push set button push flag
          if (BUTTON11 == 0) { button11push = 1; }
          // ***** Set LED states to on or off
          LEDY15 = 1, LEDY30 = 1, LEDR33 = 1, LEDR34 = 0, LEDR31 = 0, LEDB32 = 0, LEDB14 = 0, LEDB16 = 0, LEDB17 = 0;
          // Delay to display previous LED state
          mDelaymS(70);
          // If we see button push set button push flag
          if (BUTTON11 == 0) { button11push = 1; }
          // ***** Set LED states to on or off
          LEDY15 = 1, LEDY30 = 1, LEDR33 = 1, LEDR34 = 0, LEDR31 = 0, LEDB32 = 0, LEDB14 = 0, LEDB16 = 0, LEDB17 = 0;
          // Delay to display previous LED state
          mDelaymS(70);
          // If we see button push set button push flag
          if (BUTTON11 == 0) { button11push = 1; }
          // ***** Set LED states to on or off
          LEDY15 = 1, LEDY30 = 1, LEDR33 = 1, LEDR34 = 0, LEDR31 = 0, LEDB32 = 0, LEDB14 = 0, LEDB16 = 0, LEDB17 = 0;
          // Delay to display previous LED state
          mDelaymS(70);
          // If we see button push set button push flag
          if (BUTTON11 == 0) { button11push = 1; }
          // ***** Set LED states to on or off
          LEDY15 = 1, LEDY30 = 1, LEDR33 = 1, LEDR34 = 0, LEDR31 = 0, LEDB32 = 0, LEDB14 = 0, LEDB16 = 0, LEDB17 = 0;
          // Delay to display previous LED state
          mDelaymS(70);
          // If we see button push set button push flag
          if (BUTTON11 == 0) { button11push = 1; }
          // ***** Set LED states to on or off
          LEDY15 = 1, LEDY30 = 1, LEDR33 = 1, LEDR34 = 0, LEDR31 = 0, LEDB32 = 1, LEDB14 = 0, LEDB16 = 0, LEDB17 = 0;
          // Delay to display previous LED state
          mDelaymS(70);
          // If we see button push set button push flag
          if (BUTTON11 == 0) { button11push = 1; }
          // ***** Set LED states to on or off
          LEDY15 = 1, LEDY30 = 1, LEDR33 = 1, LEDR34 = 0, LEDR31 = 0, LEDB32 = 1, LEDB14 = 1, LEDB16 = 0, LEDB17 = 0;
          // Delay to display previous LED state
          mDelaymS(70);
          // If we see button push set button push flag
          if (BUTTON11 == 0) { button11push = 1; }
          // ***** Set LED states to on or off
          LEDY15 = 1, LEDY30 = 1, LEDR33 = 1, LEDR34 = 0, LEDR31 = 0, LEDB32 = 0, LEDB14 = 1, LEDB16 = 1, LEDB17 = 0;
          // Delay to display previous LED state
          mDelaymS(70);
          // If we see button push set button push flag
          if (BUTTON11 == 0) { button11push = 1; }
          // ***** Set LED states to on or off
          LEDY15 = 1, LEDY30 = 1, LEDR33 = 1, LEDR34 = 0, LEDR31 = 0, LEDB32 = 0, LEDB14 = 0, LEDB16 = 1, LEDB17 = 1;
          // Delay to display previous LED state
          mDelaymS(70);
          // If we see button push set button push flag
          if (BUTTON11 == 0) { button11push = 1; }
          // ***** Set LED states to on or off
          LEDY15 = 1, LEDY30 = 1, LEDR33 = 1, LEDR34 = 0, LEDR31 = 0, LEDB32 = 0, LEDB14 = 0, LEDB16 = 0, LEDB17 = 1;
          // Delay to display previous LED state
          mDelaymS(70);
          // If we see button push set button push flag
          if (BUTTON11 == 0) { button11push = 1; }
          // ***** Set LED states to on or off
          LEDY15 = 1, LEDY30 = 1, LEDR33 = 1, LEDR34 = 1, LEDR31 = 0, LEDB32 = 0, LEDB14 = 0, LEDB16 = 0, LEDB17 = 0;
          // Delay to display previous LED state
          mDelaymS(70);
          // If we see button push set button push flag
          if (BUTTON11 == 0) { button11push = 1; }
          // ***** Set LED states to on or off
          LEDY15 = 1, LEDY30 = 1, LEDR33 = 1, LEDR34 = 0, LEDR31 = 1, LEDB32 = 0, LEDB14 = 0, LEDB16 = 0, LEDB17 = 0;
          // Delay to display previous LED state
          mDelaymS(70);
          // If we see button push set button push flag
          if (BUTTON11 == 0) { button11push = 1; }
          // ***** Set LED states to on or off
          LEDY15 = 1, LEDY30 = 0, LEDR33 = 1, LEDR34 = 1, LEDR31 = 0, LEDB32 = 0, LEDB14 = 0, LEDB16 = 0, LEDB17 = 0;
          // Delay to display previous LED state
          mDelaymS(70);
          // If we see button push set button push flag
          if (BUTTON11 == 0) { button11push = 1; }
          // ***** Set LED states to on or off
          LEDY15 = 1, LEDY30 = 1, LEDR33 = 1, LEDR34 = 0, LEDR31 = 1, LEDB32 = 0, LEDB14 = 0, LEDB16 = 0, LEDB17 = 0;
          // Delay to display previous LED state
          mDelaymS(70);
          // If we see button push set button push flag
          if (BUTTON11 == 0) { button11push = 1; }
          // ***** Set LED states to on or off
          LEDY15 = 1, LEDY30 = 1, LEDR33 = 1, LEDR34 = 1, LEDR31 = 0, LEDB32 = 0, LEDB14 = 0, LEDB16 = 0, LEDB17 = 0;
          // Delay to display previous LED state
          mDelaymS(70);
          // If we see button push set button push flag
          if (BUTTON11 == 0) { button11push = 1; }
          // ***** Set LED states to on or off
          LEDY15 = 1, LEDY30 = 1, LEDR33 = 1, LEDR34 = 0, LEDR31 = 1, LEDB32 = 0, LEDB14 = 0, LEDB16 = 0, LEDB17 = 0;
          // Delay to display previous LED state
          mDelaymS(70);
          // If we see button push set button push flag
          if (BUTTON11 == 0) { button11push = 1; }
          // ***** Set LED states to on or off
          LEDY15 = 1, LEDY30 = 1, LEDR33 = 1, LEDR34 = 1, LEDR31 = 0, LEDB32 = 0, LEDB14 = 0, LEDB16 = 0, LEDB17 = 0;
          // Delay to display previous LED state
          mDelaymS(70);
          // If we see button push set button push flag
          if (BUTTON11 == 0) { button11push = 1; }
          // ***** Set LED states to on or off
          LEDY15 = 1, LEDY30 = 1, LEDR33 = 0, LEDR34 = 0, LEDR31 = 1, LEDB32 = 0, LEDB14 = 0, LEDB16 = 0, LEDB17 = 0;
          // Delay to display previous LED state
          mDelaymS(70);
          // If we see button push set button push flag
          if (BUTTON11 == 0) { button11push = 1; }
          // ***** Set LED states to on or off
          LEDY15 = 1, LEDY30 = 1, LEDR33 = 0, LEDR34 = 1, LEDR31 = 0, LEDB32 = 0, LEDB14 = 0, LEDB16 = 0, LEDB17 = 0;
          // *****
          // ***** End of this LED mode
          // *****
        }
        // ********************************
        // ***** LED MODE ADJUSTMENTS *****
        // ********************************
        // If button was pushed during the cycle above then flag should be set
        if (button11push == 1) {
          // Increase LED Mode value
          ledmode = ledmode + 1;
          // Check if LED Mode value is beyond max value and if so set to min value
          if (ledmode > 3) { ledmode = 1; }
          // Reset button push flag
          button11push = 0;
        }
        // ********************************
        // ****** END OF MODE LOOPS *******
        // ********************************
    }
    // ********************************
    // ***** END OF PRIMARY LOOP ******
    // ********************************
}

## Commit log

2020-01-20 Initial Template Upload
    [Battery_Holder_3xAAA_Simple.step, CP_Radial_D6.3mm_P2.50mm.step, C_0805_2012Metric.step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]
2020-03-10 Started dev board work
2020-03-21 Added 0603 components
    [C_0603_1608Metric.step, LED_0603_1608Metric.step, LED_0603_1608Metric_Castellated.step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]
2020-03-22 development board finished
    [dev-B_Cu.gbl, dev-B_Mask.gbs, dev-B_Paste.gbp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]
2020-04-08 basic code for dev board
2020-05-01 Started work on prod board
    [prod.kicad_pcb, prod.sch]
2020-05-01 Badge PCB layout work
    [prod.kicad_pcb]
2020-05-02 More PCB Layout work
    [prod.kicad_pcb]
2020-05-03 84 badge completed sent to prototype
    [84badgeprod-B_Cu.gbl, 84badgeprod-B_Mask.gbs, 84badgeprod-B_Paste.gbp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]
2020-05-13 Updates to LED flashing in Prod code.
2020-06-14 Adjustments to silkscreen art based on prototype run
    [prod-B_Cu.gbl, prod-B_Mask.gbs, prod-B_Paste.gbp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]
2022-10-06 Bump activesupport from 6.0.3 to 6.0.6 in /docs
    Bumps [activesupport](https://github.com/rails/rails) from 6.0.3 to 6.0.6.
    - [Release notes](https://github.com/rails/rails/releases)
    - [Changelog](https://github.com/rails/rails/blob/v7.0.4/activesupport/CHANGELOG.md)
    - [Commits](https://github.com/rails/rails/compare/v6.0.3...v6.0.6)
    ---
    updated-dependencies:
    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

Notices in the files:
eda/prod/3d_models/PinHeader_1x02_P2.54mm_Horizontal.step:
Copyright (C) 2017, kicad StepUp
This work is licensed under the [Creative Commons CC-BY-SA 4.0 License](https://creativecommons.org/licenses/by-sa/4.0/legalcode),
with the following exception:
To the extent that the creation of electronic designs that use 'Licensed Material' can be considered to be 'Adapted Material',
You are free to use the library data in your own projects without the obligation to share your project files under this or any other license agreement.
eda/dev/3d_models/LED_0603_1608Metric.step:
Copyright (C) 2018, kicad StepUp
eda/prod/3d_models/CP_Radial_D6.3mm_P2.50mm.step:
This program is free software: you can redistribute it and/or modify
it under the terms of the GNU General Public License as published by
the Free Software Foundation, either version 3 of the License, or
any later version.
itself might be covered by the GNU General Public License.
